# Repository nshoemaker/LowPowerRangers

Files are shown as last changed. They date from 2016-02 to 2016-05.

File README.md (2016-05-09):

# LowPowerRangers
###2D TOF RF Tracking from a Single Sensor Bar
####18-549 Capstone Project for Team 20
####Clayton Ritcher, Nora Shoemaker, and Shashwat Srivastava
#####For more information, check out our website
https://www.ece.cmu.edu/~ece549/spring16/team20/website/
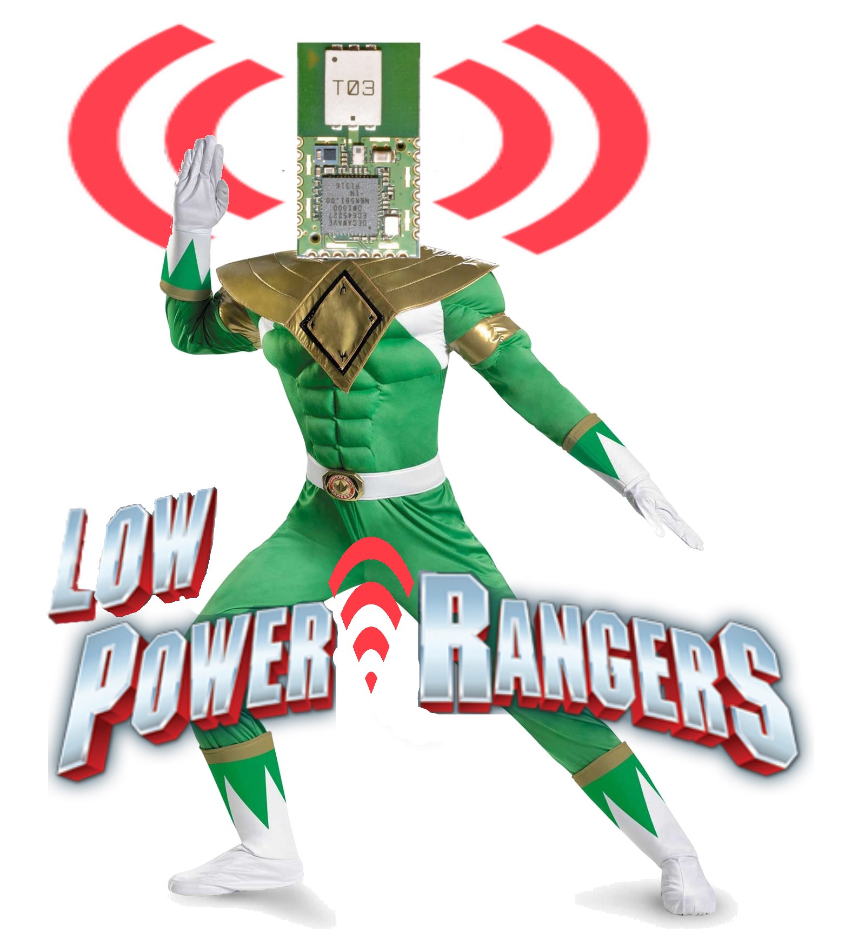
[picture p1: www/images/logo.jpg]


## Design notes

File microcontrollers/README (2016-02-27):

To Build:

	For each microcontroller (one time):
		1) Remove the 3 volt regulator
		2) Plug the ISP programmer cable into the board (the actual cable faces away from ground and 5v)
		3) cd into the bootloader directory
		4) Run 'sudo make atmega328_pro8_isp'
		5) Put the 3 volt regulator back

	For tags:
		1) cd into the src/tag folder
		2) Run 'sudo make program'

	For anchors:
		1) cd into the src/anchor folder
		2) Run 'sudo make program'

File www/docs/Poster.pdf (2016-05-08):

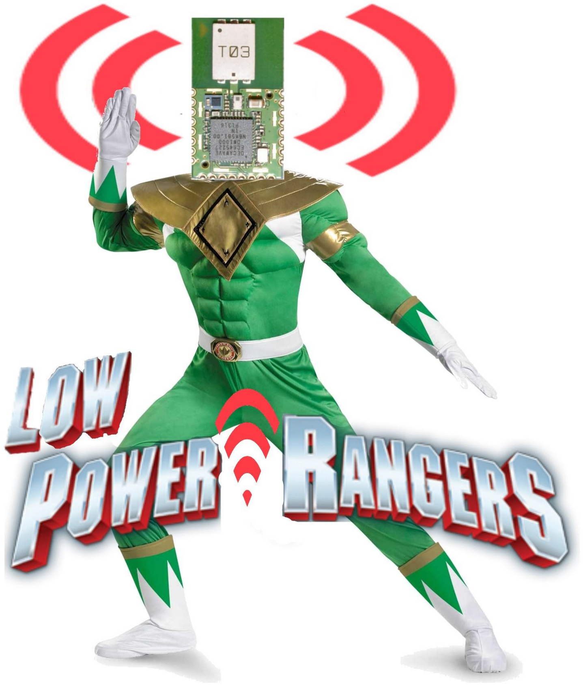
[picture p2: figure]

Electrical and Computer Engineering Department Carnegie Mellon University Clayton Ritcher, Nora Shoemaker, Shashwat Srivastava {critcher, nshoemak, shashwas}@andrew.cmu.edu
https://www.ece.cmu.edu/~ece549/spring16/team20/website/

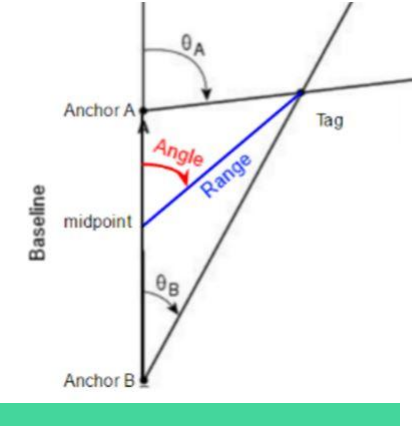
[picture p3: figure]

## Communication Protocol

## Concept

### 18-549 Embedded Design Capstone S’16

## Hardware

The goal of our project is to create a real-time, indoor localization web API for measuring and reporting relative angle and range information of an object.

Using three Ultrawide Band (UWB) radios and a time of flight (TOF) based ranging protocol, we can successfully track the range of an object within 5% accuracy and angle within 10° (0.15 rad) accuracy.

In order to collect ranging
information | with | the | UWB
radios, we needed to define and
implement | our | | own
communication protocol. Below is a diagram showing the
messages needed to be passed between the two Anchors and the Tag in order to collect TOF information to determine range.

A large part of our project involved research
into | how | baseline | distances | (between
Anchors) affect the accuracy of the angle and range measurements.

## Baseline Research

We created a single printed circuit board (PCB) for both the Anchors and the Tag (the roles are defined in software, not hardware). The boards let us connect the DWM1000 UWB
radios | to | our | ATMEGA328
microcontrollers.

## Architecture

The trilateration equations show that as the baseline increases, angle measurements
become | more | resilient | to | individual
measurement error. This is supported by the top graph above. Additionally, the equations show that range measurements are more robust to noise as the range grows compared to the baseline. Again, our bottom graph follows this trend.

All data shown was collected at an angle of 45°.

## Quick Facts

- To achieve our 10 cm single tag-anchor range accuracy, message flight time measurements must be accurate within ⅓ of a nanosecond
- That’s nearly 100 times shorter than one clock cycle of our radio or microprocessor
- Clock drift on the radios, if not handled in the ranging protocol, can cause error of up to 12 meters
- UWB-based localization is very new. BLE or WiFi solutions have ~5m accuracy

Indoor localization has many uses:
- Indoor GPS-style navigation
- Robotics
- Targeted advertising
- Inventory tracking
- Augmented reality
and more

## Applications

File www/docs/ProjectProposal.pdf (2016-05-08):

# 18-549 Design Proposal

## Team 20: Low Power Rangers

Clayton Ritcher (critcher)
Nora Shoemaker (nshoemak)
Shashwat Srivastava (shashwas)

2/12/2016

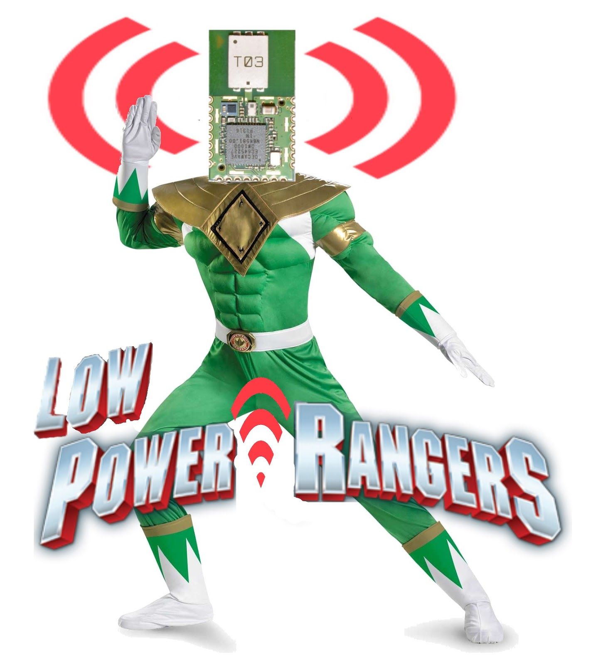
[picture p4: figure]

# Table of Contents

Project Description | 2
Design Requirements | 2
Architecture | 3
Design Trade Studies | 4
System Description/Depiction | 6
Schedule | 8
Team Member Responsibilities | 10
Budget | 10
Risk Management | 11
Related Work | 12
References | 12

# Project Description

The main goal of this project is to use two Decawave DWM1000 ultra wide band (UWB) radio transceiver to collect angle of arrival and range information of a single other transceiver relative to the measurement unit. We will call the two transceivers in the measurement device Anchors, and the other device a Tag. Because angle of arrival detection has never been done before publicly with UWB, we want to explore the space and experiment with different configurations in order to evaluate what kind of accuracy we can achieve at various baseline distances between the Anchors.

On top of this, we would like to expose a web API for accessing the angle of arrival and range data collected. Applications that would like to use these data can then be built on top of our API.

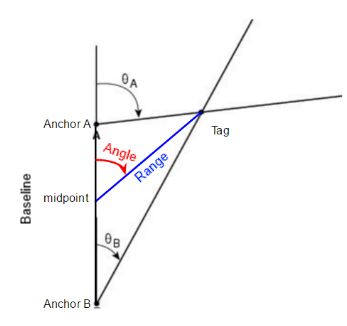
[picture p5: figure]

# Design Requirements

Motivations:

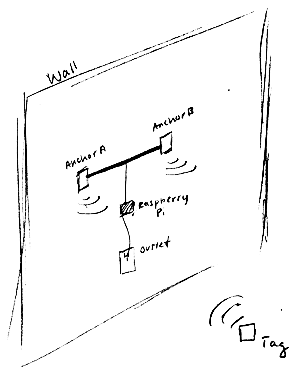
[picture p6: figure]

M1. Locationfocused client applications want near realtime range and angle tracking of users.
M2. Client applications want information to be easily accessible and platform independent.
M3. Useful client applications will necessitate that the tracked object be mobile and always on.
M4. We want to keep the scope of our project reasonable if a feature does not supplement the demo, it is likely unnecessary.

Primary Requirements:
PR1. Range and angle data shall be available through a webaccessible API [M2].
PR2. Range and angle data should be available through the API in under two seconds after the data is collected [M1].
PR3. Range and angle data shall be collected at a rate of at least 1 Hz [M1].
PR4. Tag shall be portable (battery powered) as to allow tracking of mobile objects [M3].
PR5. Tag shall be able to run at least two hours on a full battery [M3].
PR6. Webserver shall be able to handle load of up to 100 requests per second [M2,M4].

Stretch Goals (possible extensions, in no particular order):
SG1. A ‘radar’ app for finding your keys, phone, etc (anything with a Tag attached).
SG2. A client app that integrates the system with IFTTT, (https://ifttt.com/) allowing actions such as turning on the TV when you sit on the couch.
SG3. Add a third Anchor, making an ‘L’ with the other two, in order to measure both the vertical and horizontal angle of arrival.
SG4. Ability to change the baseline distance between the measurement Anchors without manually changing the configuration parameters in the code.

# Architecture

Below is a physical architectural diagram showing the components of our project and the various forms of communication that the components use amongst themselves.

UWB communication is used to obtain the range data between each of the Anchors and the Tag using TOF analysis. Microcontrollers on each Tag/Anchor talk to the DWM1000 chip through SPI. Once each of the Anchors know their distance from the Tag, this information will be sent to the Raspberry Pi, along with the Tag ID. The Raspberry Pi will then compute the angle of arrival based on the two range estimates and the known distance between the Anchors. Once the angle of arrival is calculated, the range between the Tag and the midpoint of the Anchors will be calculated and these two pieces of data will be sent to the web server, with the Tag and measurement device IDs, through an internal API call.

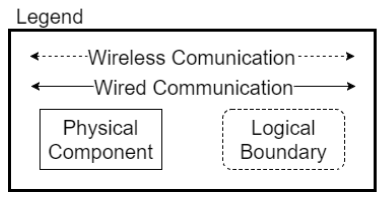
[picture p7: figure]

# Design Trade Studies

A major trade study we conducted involved the general message protocol that we plan to use for ranging. To fulfill our requirements, our system must be able to calculate the distance from each of the two Anchors to the Tag at a rate of at least 1 Hz. Additionally, we wish to keep the power consumption of the Tag low so that it can be battery powered, and we wish to achieve the highest accuracy that we can. Ideally, the protocol that we use will allow for Tag discovery, as well.

One ranging protocol is Singlesided twoway ranging (SS-TWR). This protocol involves two messages total and allows a propagation time to be calculated by the initiating device based on the time the other device takes to reply, Treply and the round trip time experienced by the initiating device, Tround

. Then, the propagation
time can be calculated as:
Tprop = (T | T | ) 2

1

### round − reply

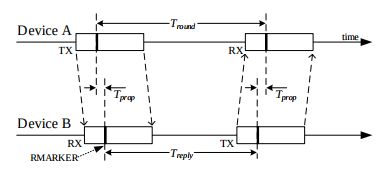
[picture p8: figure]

Figure 2. The twomessage ranging scheme defined by SS-TWR.

1

Another ranging protocol we considered is Doublesided twoway ranging (DS-TWR). This protocol uses three messages and varies from SS-TWR in two main ways because of the extra message. First, this protocol can account for error due to clock drift between the devices. Second, this protocol calculates the range on the second device, not the initiator.

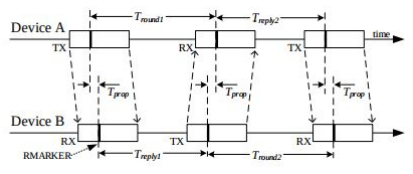
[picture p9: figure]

Figure 3. The threemessage ranging scheme defined by DS-TWR.

1

With DS-TWR, the propagation time is then calculated as:

### Tprop =

(T | T | − T | T | )
| round1 * round2 | | reply1 * reply2
(T | + T | + T | + T | )
round1 | round2 | reply1 | reply2

A final ranging protocol we considered is Broadcastdoublesided ranging (BDSR). This protocol is similar to DS-TWR, but cuts down on the number of messages needed when the initiator is ranging with multiple other devices. This is achieved by having the Tag broadcast its messages and letting all other devices respond in a stagger.

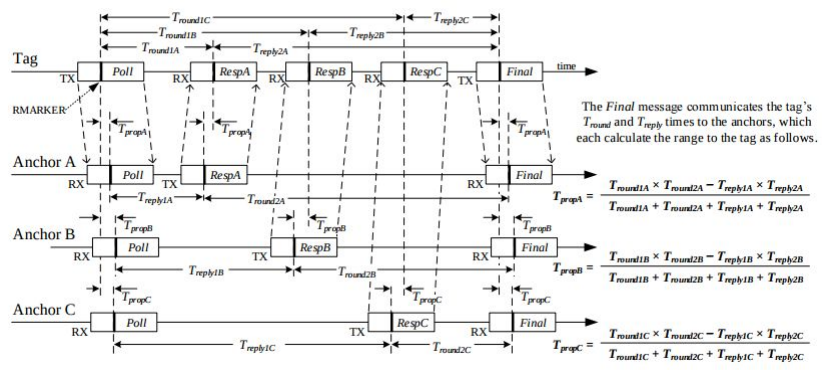
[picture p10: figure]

Figure 4. BDSR with three other devices (Anchor A-C). Each Anchor calculates its range from the initiator as shown on the right.

1

Using the criteria listed above, we decided to evaluate these three protocols against one another:

(All Scores Between 1 and 5) | Weight (higher is more important) | SS-TWR | DS-TWR | BDSR
Possible Update Rate | 2 | 4 | 1 | 4
Tag Power Consumption | 3 | 1 | 3 | 4
Achievable Accuracy | 4 | 1 | 4 | 4
Tag Discovery | 1 | 0 | 0 | 5
Total (higher is better) | | 15 | 27 | 41

As you can see, we decided on BDSR as our ranging protocol. One reason for this is that, for two Anchors, each ranging session only requires four messages. DS-TWR would require six (three for each Anchor), and while SS-TWR only takes four as well, the number of messages needs scales twice as fast with the number of Anchors for SS-TWR. Thus, BDSR will perform better if we decide to add Anchors.

Additionally, because the Tag initiates the ranging (and thus is not constantly listening) and only has to send two messages (regardless of the number of Anchors), BDSR allows for the lowest Tag power consumption. Furthermore, BDSR allows for measurements as accurate as DS-TWR, and more accurate than SS-TWR (which does not handle clock drift). Finally, because the Tag only sends broadcast messages in BDSR, Tag discovery is integrated (the devices do not need to know each others addresses).

# System Description/Depiction

The goal of our system is to collect range and angle of arrival information about a single Tag, relative to a measurement device, over a period of time and create a web API from which applications can retrieve this information.

The diagram shows the interaction between various components going through the process of collecting range and angle of arrival information for a single point in time.
Steps:
1. Poll Tag polls both Anchors in a broadcasted message.
2. ResponseA Anchor A sends response to Tag. 3.ResponseB Anchor B sends response to Tag. 4.Final Tag broadcasts Final message to Anchors containing enough information for each Anchor to estimate range.
5.Anchors tell Raspberry Pi their newly calculated range values.
6. Raspberry Pi calculates angle of arrival and then makes API call to store new data on the Webserver.

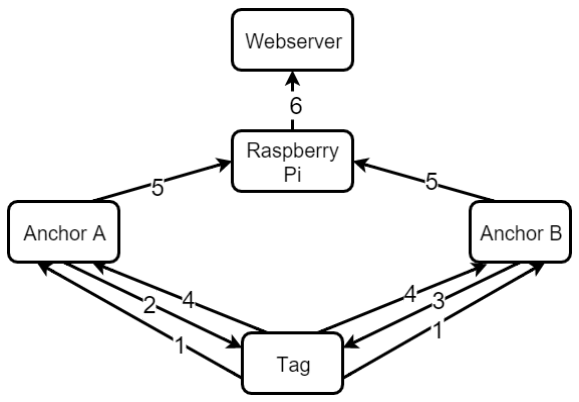
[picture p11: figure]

Part of the interaction is the UWB
communication protocol we will use. We chose a variant of the BDSR protocol described in Figure 4. Because we only intend to use two Anchors, we plan on using something similar to the protocol below:

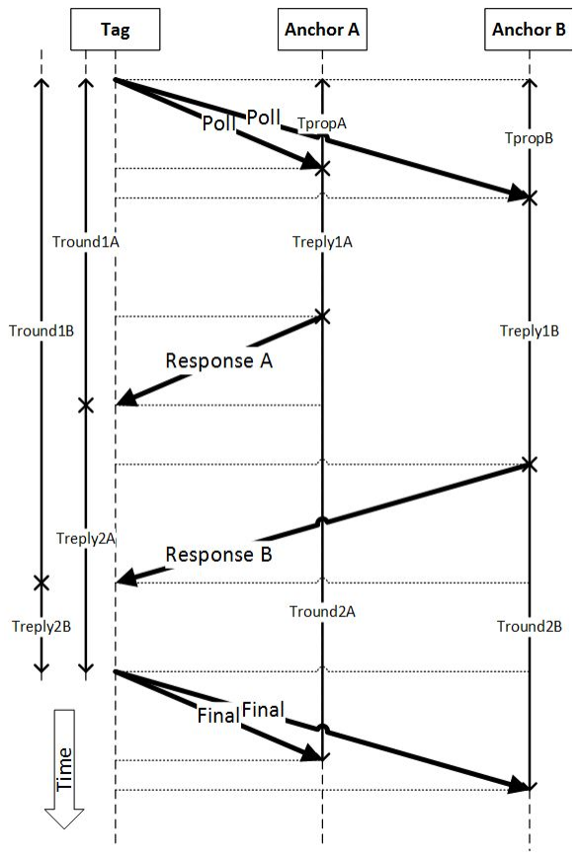
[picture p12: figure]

Protocol Step | Information Sent
Poll | Range Session ID, Tag Address
Response | Range Session ID, Anchor ID
Final | Range Session ID, Tag Address, Tround1A, Treply2A, Treply1B, Treply2B

With this protocol, the propagation times, and thus the ranges can be determined for Anchor A and Anchor B as follows:

### TpropA =

(T | T | − T | T | )
| round1A * round2A | | reply1A * reply2A
(T | + T | + T | + T | )
round1A | round2A | reply1A | reply2A

### TpropB =

(T | T | − T | T | )
| round1B * round2B | | reply1B * reply2B
(T | + T | + T | + T | )
round1B | round2B | reply1B | reply2B

One thing to note is that when we refer to a ‘Tag’ or an ‘Anchor’ we are referring to the microcontroller / DWM1000 pairs, as specified in the architecture section earlier. Therefore, when we say something such as

‘the Tag sends a message’ we are abstracting away the fact that the microcontroller is actually setting registers on the DWM1000 over SPI in order to command the module to send the message.

At a higher level, our project itself has very little user interaction (by design, for ease of use); the user simply needs to carry a Tag with them while in the presence of a measurement device to use the system itself. However, here is what we would expect user interaction with a client application to look like:

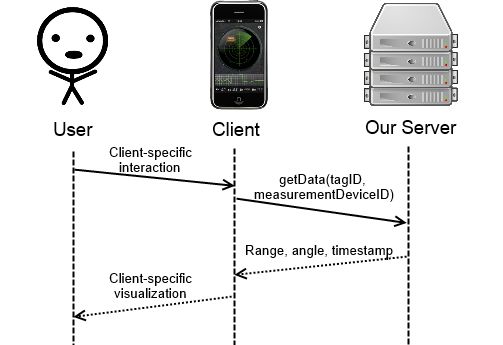
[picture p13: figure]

# Schedule

Because we have such a hard deadline presented by the demo, we are planning on finishing our project in six weeks (half the time left in the semester). We want to make clear that we are planning on finishing in six weeks with the expectation that it will end up taking longer than that to finish our nonstretch goals. We want to factor in our inevitable misestimations and allow for significant padding so that we can truly be finished by the demo date.

(Please zoom in on the schedule on the next page for full details)

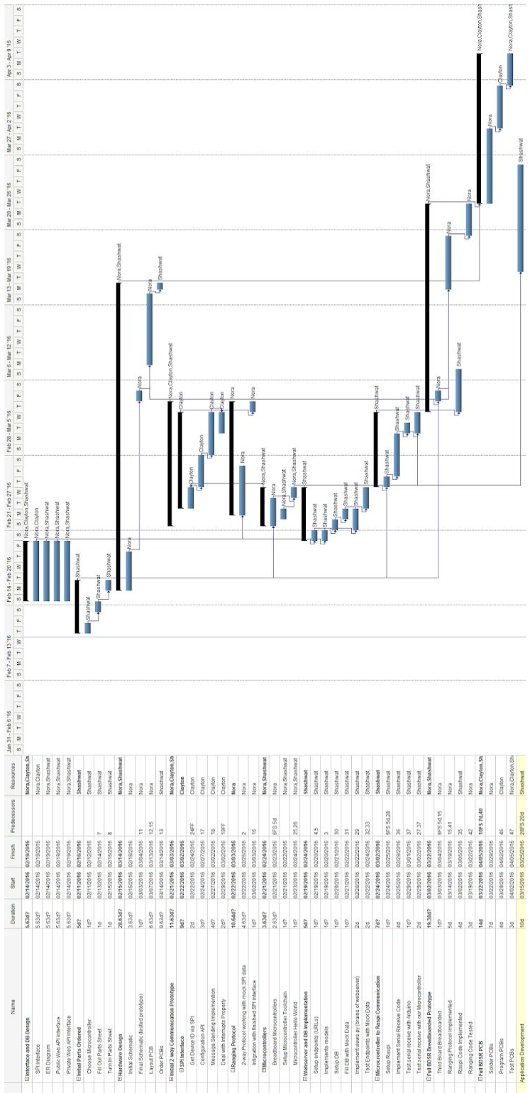
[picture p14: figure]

# Team Member Responsibilities

We plan on breaking down the project into smaller tasks. Each task will have an “owner” who is in charge of it being completed. While it is the owner’s responsibility to finish the task, everyone can work on it. See the schedule for finer grained breakdown of tasks.

Task | Person in Charge
Creating an SPI interface to control the UWB module | Clayton Ritcher
Creating/Implementing a protocol for Tag discovery and ranging | Nora Shoemaker
Sending data from the Microcontroller to the Raspberry Pi | Clayton Ritcher
Sending data from the Raspberry Pi to the server | Shashwat Srivastava
Making data available to an API | Shashwat Srivastava
Making application on top of data (NOTE: Stretch goal) | Shashwat Srivastava
Web Master | Nora Shoemaker
Creating the PCB Design | Nora Shoemaker
Hardware Construction | Nora Shoemaker

# Budget

Part | Cost | Link for part | Quantity | Total Cost
Raspberry Pi | $49.95 | https://www.sparkfun.com/products/13724 | 1 | $49.95
Wifi Adapter for Raspberry Pi | $14.95 | https://www.sparkfun.com/products/13677 | 1 | $14.95
Decawave DWM1000 Module | $20.50 | http://www.semiconductorstore.com/cart/pc/viewPrd.asp?idproduct=50013 (http://www.semiconductorstore.com/cart/pc/viewPrd.asp?idproduct=50013) | 7 | $143.50
Pocket AVR Programmer | $14.95 | https://www.sparkfun.com/products/9825 | 2 | $29.90
Plastic Breadboard | $4.95 | https://www.sparkfun.com/products/11317 | 3 | $14.85
ATMega 328 | $3.70 | http://www.mouser.com/ProductDetail/Atmel/ATMEGA328P-PU/?qs=K8BHR703ZXguOQv3sKbWcg%3D%3D&gclid=CjwKE | 7 | $25.90

| | AiA__C1BRDqyJOQ8_Tq230SJABWBSx nq4t6W6Tp6DzcyCqWLSnFywsY_JBwMr pBtNGaJ_HgZhoCJADw_wcB
Capacitors/resistors/ batteries | $50 | | | $50
PCB Fabricating Cost | $18 | | 5 | $90
Shipping charges(being conservative here) | $100 | | | $100
FTDI Breakout Board | $14.95 | https://www.sparkfun.com/products/9873 | 3 | $44.85
Total | | | | $563.90

# Risk Management

We have identified the use of the Decawave DWM1000 chip technology as a significant risk we are choosing to take on with this project. The use of this new technology, along with the fact that we are using it to find angle of arrival information, something that no one has done publicly yet, is a risk we have identified and thought a lot about. Our first mitigation strategy thus far has been to reduce the scope of the project. This doesn’t mitigate the risk of working with the technology entirely, but it does help by allowing us to budget more time towards getting things working in the likely chance that this will be a very hard, time consuming task. Our second mitigation strategy has been to add a significant amount of padding to our schedule and essentially frontload much of the work with the hope of gaining information as quickly as possible about the problems we will incur.

Another risk we have identified is our team’s relative lack of experience with embedded programming, especially when it comes to interfacing with real hardware. Every member of our team took 18-349 in Fall 2014. Because of this, we have plenty of experience with simulated hardware, but less experience with real, physical hardware at the embedded level. We all have a background in hobby electronics using Arduino and Raspberry Pi, but we understand that this project will be different and for that reason we expect a significant learning curve. In order to mitigate this risk, we have chosen a project that will involve the use of a single sensor and a single microcontroller. We scale by creating multiples copies of the same setup. Another mitigation strategy we would like to put in place is that we will require a fully working, breadboarded prototype before we fab our PCBs.

# Related Work

One of the primary reasons we chose our project was to research the feasibility of making angle of arrival calculation using ultrawideband transceivers, as it has not been publicly demonstrated as of yet. There are other solutions that tackle similar issues, though.

For instance, indoor localization systems using wifi

2
, BLE

3
, or even UWB

4 could all be used for similar applications as our system. Wifi and BLE systems are less accurate than UWB, though, and UWB indoorlocalization systems still require installation of at least three Anchors in each area, on separate walls. Our system would be able to support many similar applications (such as those listed in earlier sections) with the installation of a single device (with two contained Anchors) on a wall in the room. The selfcontained property of our Anchors device also means that it could be mounted to something other than a wall, such as a robot, and used to calculate relative range and angle information to a tag from what it is mounted to.

# References

1. http://www.decawave.com/support/download/file/nojs/725
2. http://redpin.org/
3. http://estimote.com/
4. http://www.timedomain.com/

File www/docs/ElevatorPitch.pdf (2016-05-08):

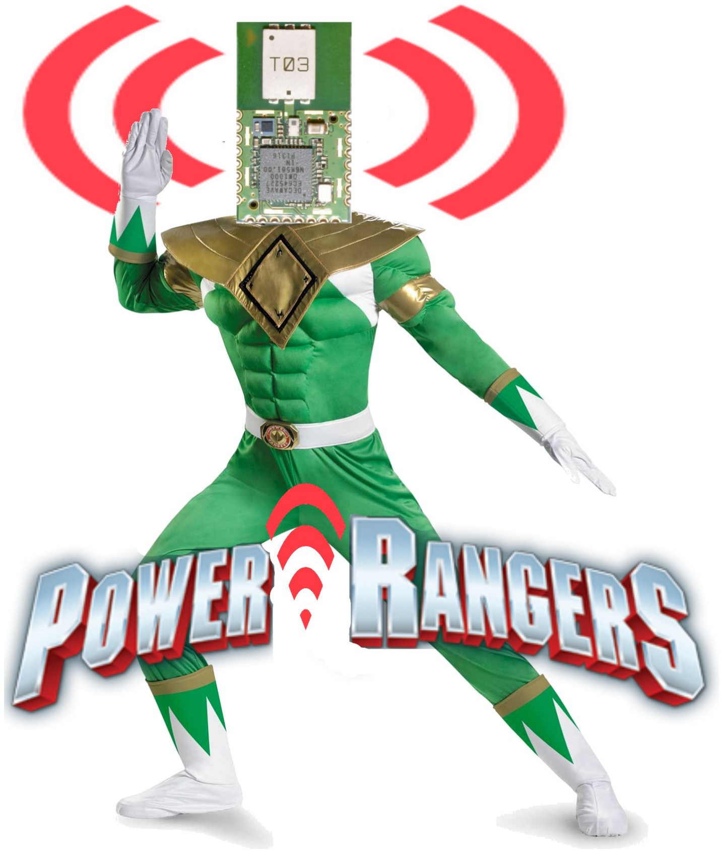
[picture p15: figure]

## Team 20 Clayton Ritcher Nora Shoemaker Shashwat Srivastava

## Concept

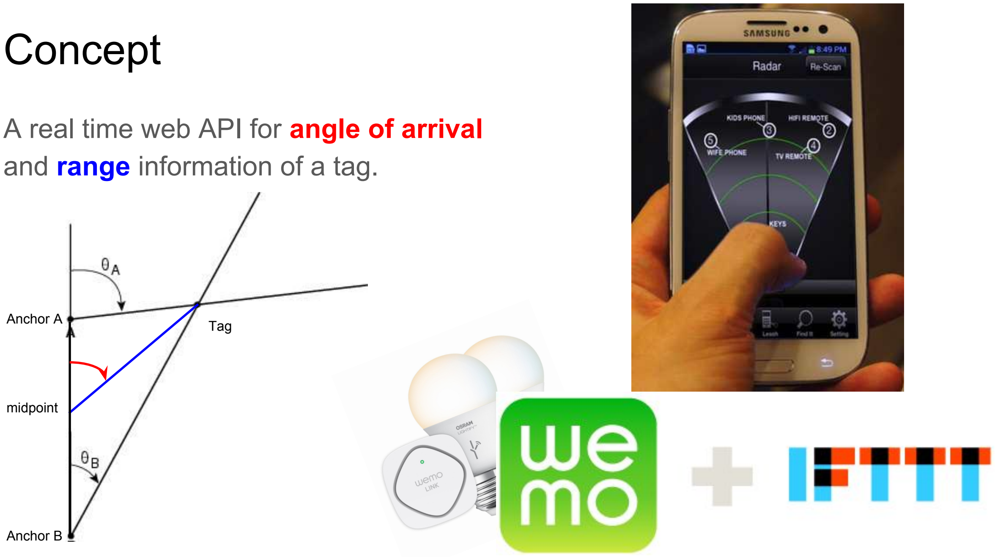
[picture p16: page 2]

A real time web API for angle of arrival and range information of a tag.

midpoint

Anchor A

Anchor B

Tag

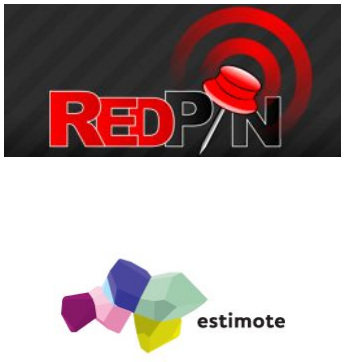
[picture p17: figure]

## Competitive Analysis

- Wifi-based
- Signal strength, fingerprint
- Often 5-10 m accuracy
- BLE Beacons
- Signal strength
- ~5 m accuracy
- UWB
- TOF
- < 1m accuracy
- Often a custom system
installation, very expensive

## Requirements

- Range and angle data shall be available to web accessible API in under two seconds after the data is collected.
- Range and angle data shall be collected at a rate of at least 1 Hz.
- Tag shall be portable (battery powered).
- Anchors and Raspberry Pi shall be powered from an outlet.
- Tag shall be able to run at least two hours on a full battery.

## Tech Specs

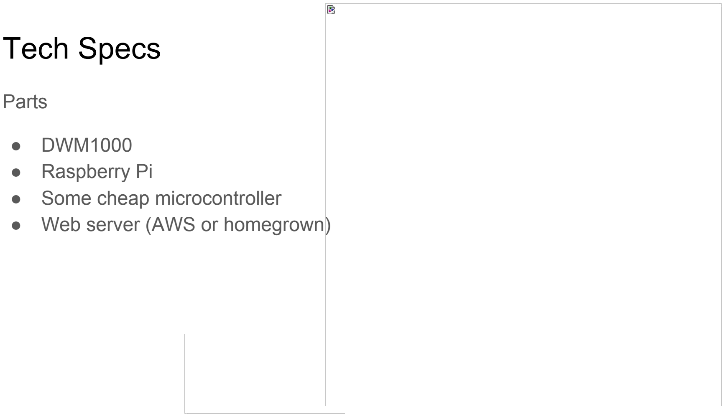
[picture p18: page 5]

Parts

- DWM1000
- Raspberry Pi
- Some cheap microcontroller
- Web server (AWS or homegrown)

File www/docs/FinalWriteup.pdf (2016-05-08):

# 18-549 Final Write Up

## Team 20: Low Power Rangers

Clayton Ritcher (critcher)
Nora Shoemaker (nshoemak)
Shashwat Srivastava (shashwas)

5/7/2016


# Table of Contents

Project Description | 2
Design Requirements | 2
Architecture | 3
Design Trade Studies | 4
System Description/Depiction | 6
Schedule | 8
Team Member Responsibilities | 10
Budget | 10
Risk Management | 11
Related Work | 12
References | 12

# Project Description

The main goal of this project is to use two Decawave DWM1000 ultra wide band (UWB) radio transceivers to collect angle of arrival and range information of a single other transceiver, relative to the measurement unit. We will call the two transceivers in the measurement device Anchors, and the other device a Tag. Because angle of arrival detection has never been done before publicly with UWB, we want to explore the space and experiment with different configurations in order to evaluate what kind of accuracy we can achieve at various baseline distances between the Anchors.

On top of this, we would like to expose a web API for accessing the angle of arrival and range data collected. Applications that would like to use these data can then be built on top of our API.


# Design Requirements

Motivations:


M1. Locationfocused client applications want near realtime range and angle tracking of users.
M2. Client applications want information to be easily accessible and platform independent.
M3. Useful client applications will necessitate that the tracked object be mobile and always on.
M4. We want to keep the scope of our project reasonable if a feature does not supplement the demo, it is likely unnecessary.

Primary Requirements:
PR1. Range and angle data shall be available through a webaccessible API [M2].
PR2. Range and angle data should be available through the API in under two seconds after the data is collected [M1].
PR3. Range and angle data shall be collected at a rate of at least 1 Hz [M1].
PR4. Tag shall be portable (battery powered) as to allow tracking of mobile objects [M3].
PR5. Tag shall be able to run at least two hours on a full battery [M3].
PR6. Webserver shall be able to handle load of up to 100 requests per second [M2,M4].

Stretch Goals (possible extensions, in no particular order):
SG1. A ‘radar’ app for finding your keys, phone, etc (anything with a Tag attached).
SG2. A client app that integrates the system with IFTTT, (https://ifttt.com/) allowing actions such as turning on the TV when you sit on the couch.
SG3. Add a third Anchor, making an ‘L’ with the other two, in order to measure both the vertical and horizontal angle of arrival.
SG4. Ability to change the baseline distance between the measurement Anchors without manually changing the configuration parameters in the code.

# Architecture

Below is a physical architectural diagram showing the components of our project and the various forms of communication that the components use amongst themselves.

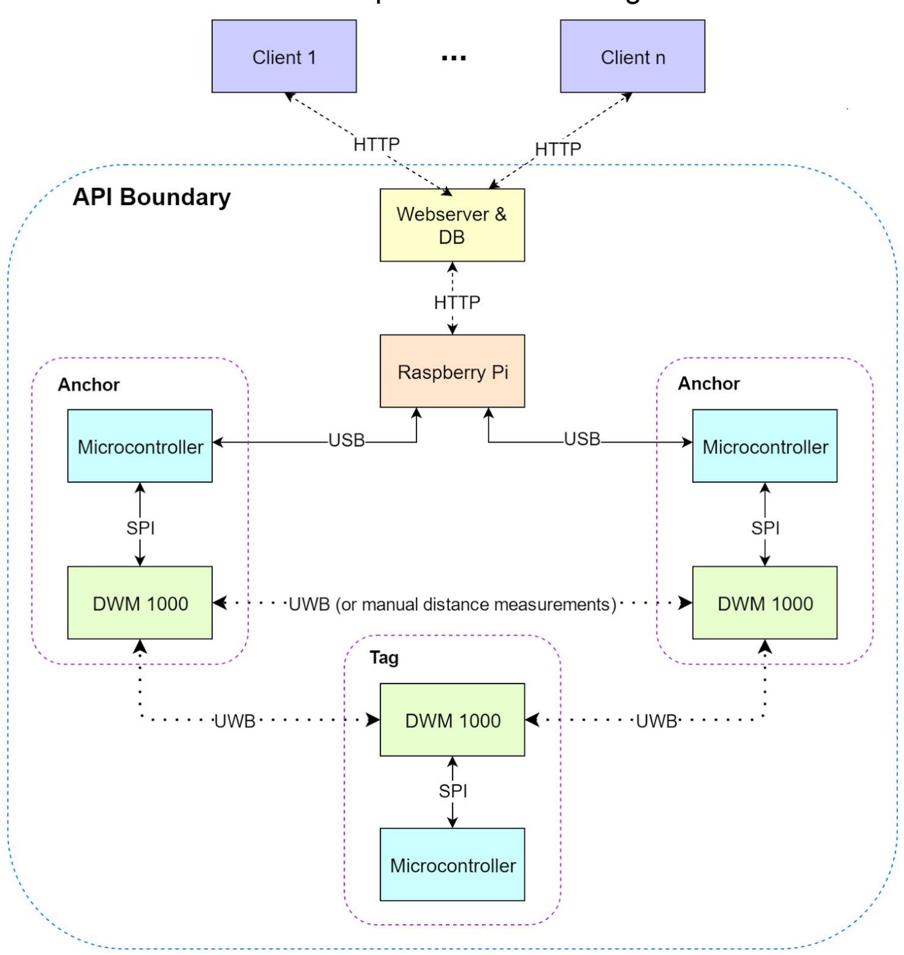
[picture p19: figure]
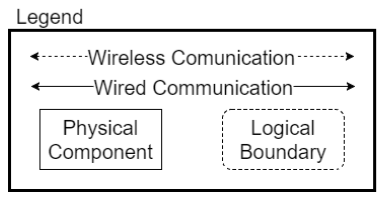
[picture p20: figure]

UWB communication is used to obtain the range data between each of the Anchors and the Tag using TOF analysis. Microcontrollers on each Tag/Anchor talk to the DWM1000 chip through SPI. Once each of the Anchors know their distance from the Tag, this information will be sent to the Raspberry Pi, along with the Tag ID. The Raspberry Pi will then compute the angle of arrival based on the two range estimates and the known distance between the Anchors. Once the angle of arrival is calculated, the range between the Tag and the midpoint of the Anchors will be calculated and these two pieces of data will be sent to the web server, with the Tag and measurement device IDs, through an internal API call.

# Design Trade Studies

A major trade study we conducted involved the general message protocol that we plan to use for ranging. To fulfill our requirements, our system must be able to calculate the distance from each of the two Anchors to the Tag at a rate of at least 1 Hz. Additionally, we wish to keep the power consumption of the Tag low so that it can be battery powered, and we wish to achieve the highest accuracy that we can. Ideally, the protocol that we use will allow for Tag discovery, as well.

One ranging protocol is Singlesided twoway ranging (SS-TWR). This protocol involves two messages total and allows a propagation time to be calculated by the initiating device based on the time the other device takes to reply, Treply and the round trip time experienced by the initiating device, Tround

. Then, the propagation
time can be calculated as:
Tprop = (T | T | ) 2

1

### round − reply


Figure 2. The twomessage ranging scheme defined by SS-TWR.

1

Another ranging protocol we considered is Doublesided twoway ranging (DS-TWR). This protocol uses three messages and varies from SS-TWR in two main ways because of the extra message. First, this protocol can account for error due to clock drift between the devices. Second, this protocol calculates the range on the second device, not the initiator.


Figure 3. The threemessage ranging scheme defined by DS-TWR.

1

With DS-TWR, the propagation time is then calculated as:

### Tprop =

(T | T | − T | T | )
| round1 * round2 | | reply1 * reply2
(T | + T | + T | + T | )
round1 | round2 | reply1 | reply2

A final ranging protocol we considered is Broadcastdoublesided ranging (BDSR). This protocol is similar to DS-TWR, but cuts down on the number of messages needed when the initiator is ranging with multiple other devices. This is achieved by having the Tag broadcast its messages and letting all other devices respond in a stagger.


Figure 4. BDSR with three other devices (Anchor A-C). Each Anchor calculates its range from the initiator as shown on the right.

1

Using the criteria listed above, we decided to evaluate these three protocols against one another:

(All Scores Between 1 and 5) | Weight (higher is more important) | SS-TWR | DS-TWR | BDSR
Possible Update Rate | 2 | 4 | 1 | 4
Tag Power Consumption | 3 | 1 | 3 | 4
Achievable Accuracy | 4 | 1 | 4 | 4
Tag Discovery | 1 | 0 | 0 | 5
Total (higher is better) | | 15 | 27 | 41

As you can see, we decided on BDSR as our ranging protocol. One reason for this is that, for two Anchors, each ranging session only requires four messages. DS-TWR would require six (three for each Anchor), and while SS-TWR only takes four as well, the number of messages needs scales twice as fast with the number of Anchors for SS-TWR. Thus, BDSR will perform better if we decide to add Anchors.

Additionally, because the Tag initiates the ranging (and thus is not constantly listening) and only has to send two messages (regardless of the number of Anchors), BDSR allows for the lowest Tag power consumption. Furthermore, BDSR allows for measurements as accurate as DS-TWR, and more accurate than SS-TWR (which does not handle clock drift). Finally, because the Tag only sends broadcast messages in BDSR, Tag discovery is integrated (the devices do not need to know each others addresses).

# System Description/Depiction

The goal of our system is to collect range and angle of arrival information about a single Tag, relative to a measurement device, over a period of time and create a web API from which applications can retrieve this information.

The diagram shows the interaction between various components going through the process of collecting range and angle of arrival information for a single point in time.
Steps:
1. Poll Tag polls both Anchors in a broadcasted message.
2. ResponseA Anchor A sends response to Tag. 3.ResponseB Anchor B sends response to Tag. 4.Final Tag broadcasts Final message to Anchors containing enough information for each Anchor to estimate range.
5.Anchors tell Raspberry Pi their newly calculated range values.
6. Raspberry Pi calculates angle of arrival and then makes API call to store new data on the Webserver.


Part of the interaction is the UWB
communication protocol we will use. We chose a variant of the BDSR protocol described in Figure 4. Because we only intend to use two Anchors, we plan on using something similar to the protocol below:


Protocol Step | Information Sent
Poll | Range Session ID, Tag Address
Response | Range Session ID, Anchor ID
Final | Range Session ID, Tag Address, Tround1A, Treply2A, Treply1B, Treply2B

With this protocol, the propagation times, and thus the ranges can be determined for Anchor A and Anchor B as follows:

### TpropA =

(T | T | − T | T | )
| round1A * round2A | | reply1A * reply2A
(T | + T | + T | + T | )
round1A | round2A | reply1A | reply2A

### TpropB =

(T | T | − T | T | )
| round1B * round2B | | reply1B * reply2B
(T | + T | + T | + T | )
round1B | round2B | reply1B | reply2B

One thing to note is that when we refer to a ‘Tag’ or an ‘Anchor’ we are referring to the microcontroller / DWM1000 pairs, as specified in the architecture section earlier. Therefore, when we say something such as

‘the Tag sends a message’ we are abstracting away the fact that the microcontroller is actually setting registers on the DWM1000 over SPI in order to command the module to send the message.

At a higher level, our project itself has very little user interaction (by design, for ease of use); the user simply needs to carry a Tag with them while in the presence of a measurement device to use the system itself. However, here is what we would expect user interaction with a client application to look like:


## Implementation and Construction

## PCB For Tag and Anchor

We decided to create the same PCB design for both Tags and Anchors.This meant the same schematic and board layout. We made this decision for a couple reasons. Using the Atmega328s on both Tag and Anchor boards meant that we would only need to write one SPI driver library to interface with the DWM1000s (whereas we could have had the Raspberry Pi communicate directly with the DWM1000s, but decided against it).

Below is an image of our final schematic. There are three main parts of our schematic.The Atmega328 chip and its associated crystal (left), the FTDI header and voltage regulator (top right), and the DWM1000 module (bottom right).

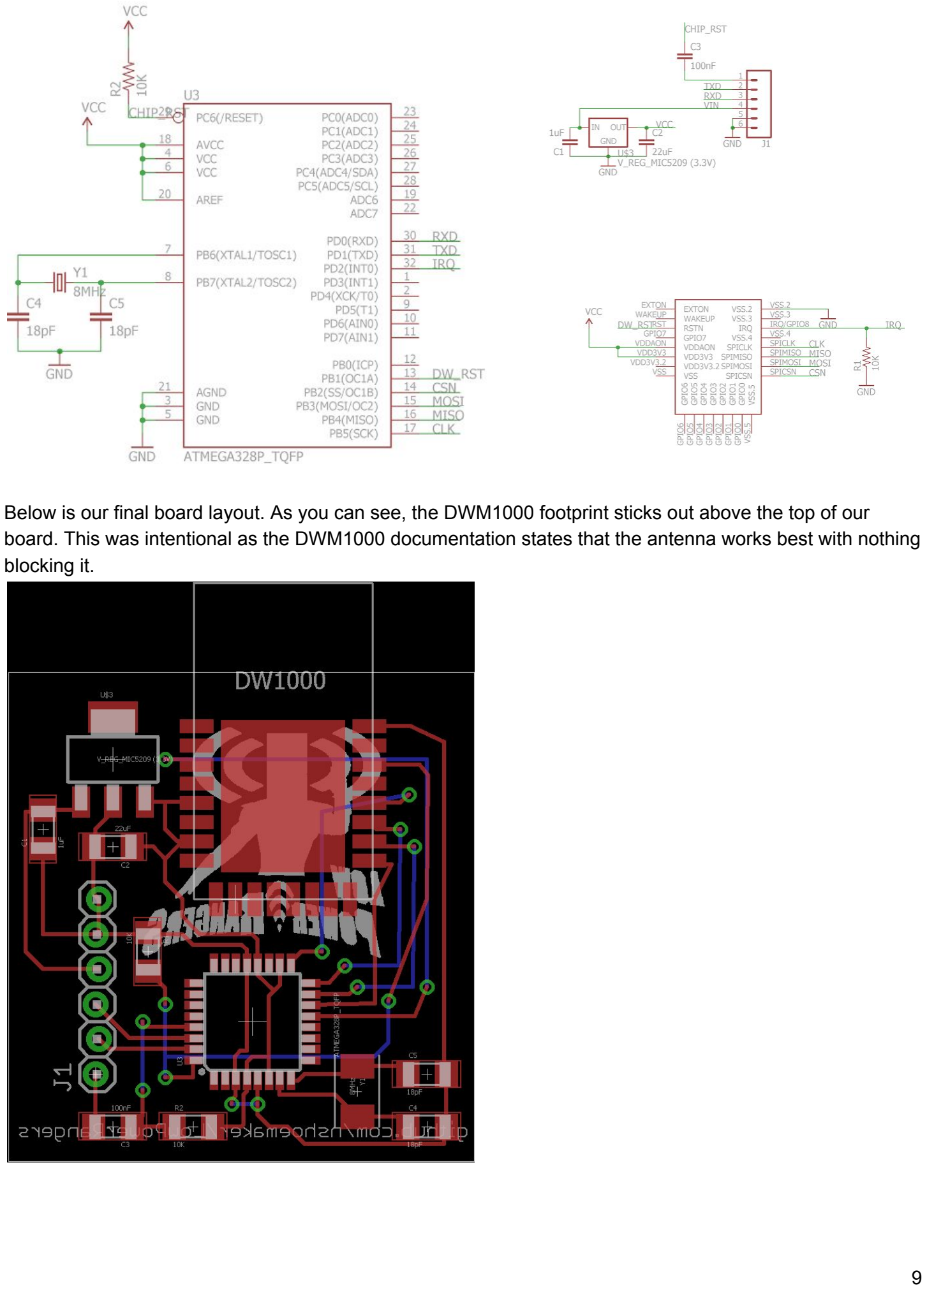
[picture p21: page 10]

Below is our final board layout. As you can see, the DWM1000 footprint sticks out above the top of our board. This was intentional as the DWM1000 documentation states that the antenna works best with nothing blocking it.

Below we have the printed circuit boards we used for both our Tags and Anchors (prebringup). We chose to put components only on one side because we wanted the option of easily laying the Anchors flat against a surface.

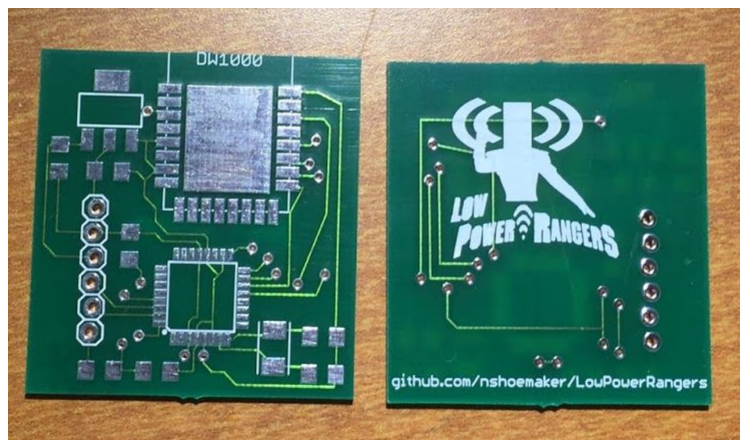
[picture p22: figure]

Here are the circuit boards after we brought them up, with the FTDI cable connected.

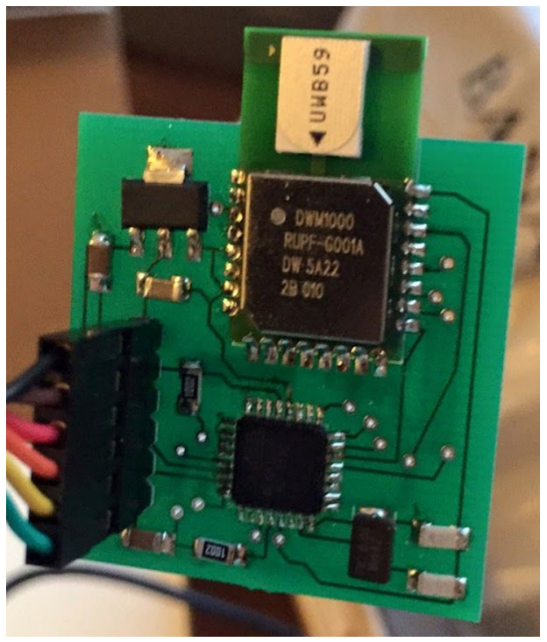
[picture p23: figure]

## Bootloader Circuit

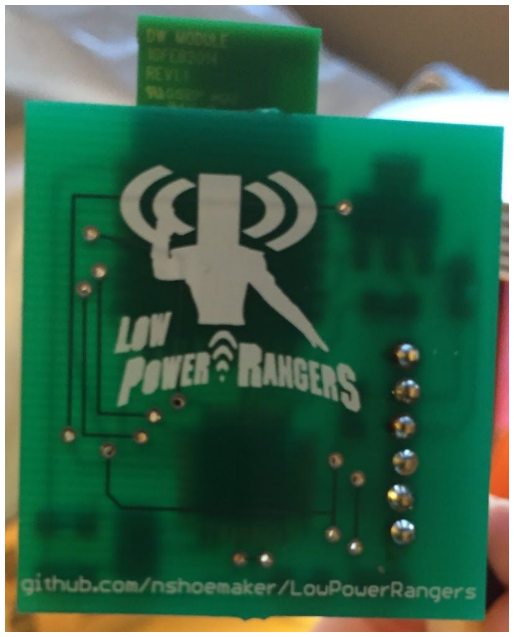
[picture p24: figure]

Another thing worth noting is that we decided to exclude the In-System Programming (ISP) circuit from our Tag and Anchor boards, opting to create an offboard ISP circuit for bootloading our microcontrollers. We decided to breadboard one bootloader circuit for ourselves, using a TQFP test socket.

5 We then soldered
the prebootloaded microcontrollers onto our board, and were able to reprogram them through the FTDI headers as needed. Below is a picture of the test socket and our bootloader circuit.

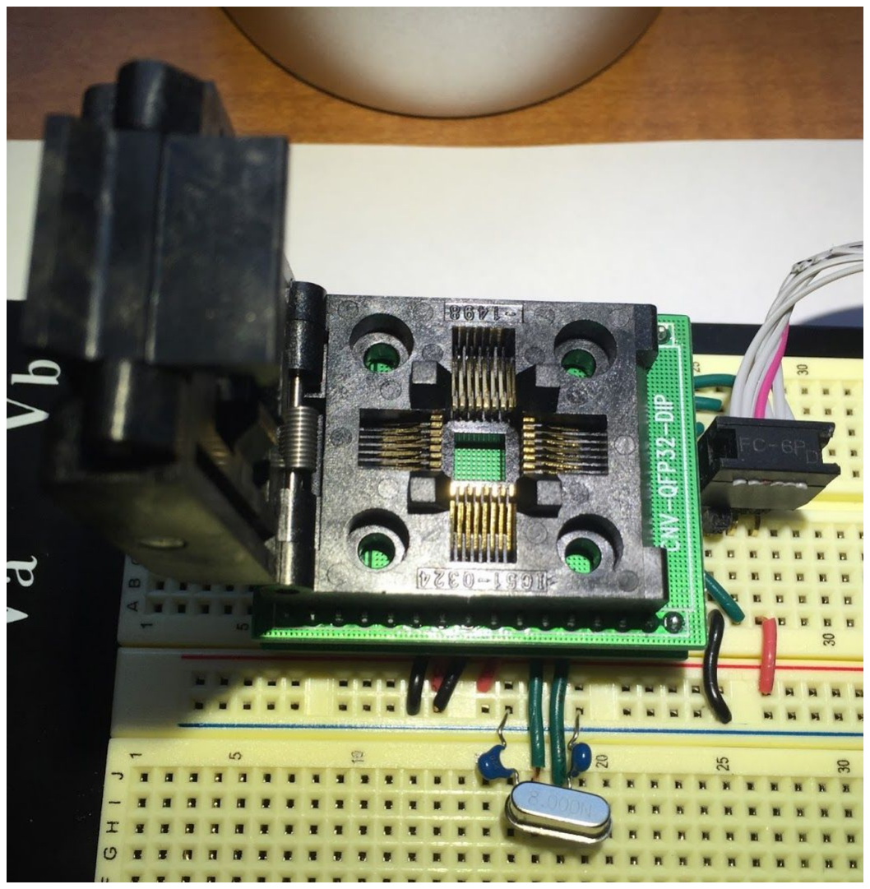
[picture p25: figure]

## Android Application

To demo the project, we built an Android application. The application would be used to display the tracking information in an intuitive way. The app pulls data from the server and then displays it on a grid.


This is the start screen. You can click on the + button to add a tag and give it a name.


Adding the tag then displays it on the screen. It will show up on the screen an appropriate distance away from the anchor positions. The angle will also be the at the correct angle from the anchor position.Below is an example tag position.


The last feature of the application can be accessed by pressing the camera button on the main screen. This will launch the camera application and allow the user to take a picture of their room from the anchor position. It will then draw a line from the bottom of the screen(assumed anchor position) to the place where the tag is. An example image is attached below


# Schedule

Because we have such a hard deadline presented by the demo, we are planning on finishing our project in six weeks (half the time left in the semester). We want to make clear that we are planning on finishing in six weeks with the expectation that it will end up taking longer than that to finish our nonstretch goals. We want to factor in our inevitable misestimations and allow for significant padding so that we can truly be finished by the demo date.

(Please zoom in on the schedule on the next page for full details)


# Team Member Responsibilities

We plan on breaking down the project into smaller tasks. Each task will have an “owner” who is in charge of it being completed. While it is the owner’s responsibility to finish the task, everyone can work on it. See the schedule for finer grained breakdown of tasks.

Task | Person in Charge
Creating an SPI interface to control the UWB module | Clayton Ritcher
Creating/Implementing a protocol for Tag discovery and ranging | Nora Shoemaker
Sending data from the Microcontroller to the Raspberry Pi | Clayton Ritcher
Sending data from the Raspberry Pi to the server | Shashwat Srivastava
Making data available to an API | Shashwat Srivastava
Making application on top of data (NOTE: Stretch goal) | Shashwat Srivastava
Web Master | Nora Shoemaker
Creating the PCB Design | Nora Shoemaker
Hardware Construction | Nora Shoemaker

# BOM

Below is the BOM needed to create our complete platform (two Anchors, one Tag, and a Raspberry Pi).

| | | | Price | $364.40
Description | Link | Quantity | Unit Price | Shipping Charge | Total Price
Programmer | https://www.sparkfun.com/products/9825 | 1 | $14.95 | | $14.95
FTDI Cable | https://www.sparkfun.com/products/9717 | 3 | $17.95 | | $53.85
Raspi | https://www.sparkfun.com/products/13724 | 1 | $49.95 | | $49.95
Wifi Dongle | https://www.sparkfun.com/products/13677 | 1 | $14.95 | | $14.95
Headers | https://www.sparkfun.com/products/12693 | 2 | $0.75 | | $1.50
Decawave | http://www.semiconductorstore.com/cart/pc/viewPrd.asp?idproduct=50013 (http://www.semiconductorstore.com/cart/pc/viewPrd.asp?idproduct=50013) | 3 | $20.50 | | $61.50
Power Supply (for Raspi) | https://www.sparkfun.com/products/13831 | 1 | $7.97 | | $7.97
MIC5209 IC REG LDO 3.3V 0.5A SOT223 | http://www.digikey.com/productdetail/en/MIC5209-3.3YS-TR/576-1274-1-ND/771899 (http://www.digikey.com/product-detail/en/MIC5209-3.3YS-TR/576-1274-1-ND/771899) | 3 | $1.19 | | $3.57

RES SMD 10K OHM 1% 1/4W 1206 | http://www.digikey.com/productdetail/en/ERJ-8ENF1002V/P10.0KFCT-ND/89822 (http://www.digikey.com/product-detail/en/ERJ-8ENF1002V/P10.0KFCT-ND/89822) | 6 | $0.10 | | $0.60
CAP CER 18PF 50V NP0 1206 | http://www.digikey.com/short/3t7p88 | 6 | $0.30 | | $1.80
CAP CER 1UF 25V X7R 1206 | http://www.digikey.com/productdetail/en/CGA5L2X7R1E105K160AA/445-6989-1-ND/2673007 (http://www.digikey.com/product-detail/en/CGA5L2X7R1E105K160AA/445-6989-1-ND/2673007) | 3 | $0.18 | | $0.54
CAP CER 0.1UF (100nF) 50V X7R 1206 | http://www.digikey.com/productdetail/en/C1206C104K5RAC7867/399-1249-1-ND/411524 (http://www.digikey.com/product-detail/en/C1206C104K5RAC7867/399-1249-1-ND/411524) | 3 | $0.07 | | $0.21
8MHz ±30ppm Crystal 18pF 80 Ohm | http://www.digikey.com/productdetail/en/7A-8.000MAAJ-T/887-1448-1-ND/2627016 (http://www.digikey.com/product-detail/en/7A-8.000MAAJ-T/887-1448-1-ND/2627016) | 3 | $0.79 | | $2.37
ATMEGA328P-A UR IC MCU 8BIT 32KB FLASH 32TQFP | http://www.digikey.com/productdetail/en/ATMEGA328P-AUR/ATMEGA328P-AURCT-ND/3789455 (http://www.digikey.com/product-detail/en/ATMEGA328P-AUR/ATMEGA328P-AURCT-ND/3789455) | 3 | $3.70 | | $11.10
SMT Test Socket TQFP-32 Breakout | https://www.adafruit.com/products/1240 | 1 | $44.95 | | $44.95
CAP CER 22UF 25V X7R 1206 | http://www.digikey.com/productdetail/en/samsungelectromechanicsamericainc/CL31A226MOCLNNC/1276-2728-1-ND/3890814 (http://www.digikey.com/product-detail/en/samsung-electro-mechanics-america-inc/CL31A226MOCLNNC/1276-2728-1-ND/3890814) | 10 | $0.29 | | $2.90
PCB order | | 1 | $85.44 | $6.25 | $91.69

# Risk Management

We have identified the use of the Decawave DWM1000 chip technology as a significant risk we are choosing to take on with this project. The use of this new technology, along with the fact that we are using it to find angle of arrival information, something that no one has done publicly yet, is a risk we have identified and thought a lot about. Our first mitigation strategy thus far has been to reduce the scope of the project. This doesn’t mitigate the risk of working with the technology entirely, but it does help by allowing us to budget more time towards getting things working in the likely chance that this will be a very hard, time consuming task. Our second mitigation strategy has been to add a significant amount of padding to our schedule and essentially frontload much of the work with the hope of gaining information as quickly as possible about the problems we will incur.

Another risk we have identified is our team’s relative lack of experience with embedded programming, especially when it comes to interfacing with real hardware. Every member of our team took 18-349 in Fall 2014. Because of this, we have plenty of experience with simulated hardware, but less experience with real, physical hardware at the embedded level. We all have a background in hobby electronics using Arduino and Raspberry Pi, but we understand that this project will be different and for that reason we expect a significant learning curve. In order to mitigate this risk, we have chosen a project that will involve the use of a single sensor and a single microcontroller. We scale by creating multiples copies of the same setup. Another mitigation strategy we would like to put in place is that we will require a fully working, breadboarded prototype before we fab our PCBs.

# Evaluation

A large part of our project involved research into how baseline distances (between Anchors) affect the accuracy of the angle and range measurements. In order to assess how different baselines affect accuracy, we needed to setup some tests. We decided to sweep out a line at 20 cm increments both at 0 degree (directly perpendicular) and 45 degree angles, using a script that collected 50 readings per increment. We repeated this process for baselines of 50, 100, 150, and 200 cm. Below are graphs of the data we collected.

### Theta Error vs. Real Distance at 0 Degrees


### Theta Error vs. Real Distance at 45 Degrees


The derivative of the trilateration equations, with respect to measurement error, shows that theta calculations are more robust to noise as the baseline increases. This can be seen in the graphs above the theta error for larger baselines is consistently lower than the theta error for smaller baselines.


### Range Error vs. Real Distance at 0 Degrees

### Range Error vs. Real Distance at 45 Degrees

The derivative of the trilateration equations, with respect to measurement error, shows that range calculations are less robust to noise as the difference between r1 and r2 (distance to each of the two anchors) grows. This can be seen in the graphs above the range error for for all baselines is very low when at 0 degrees (r1 = r2), but larger baselines have larger range error when at an angle (the larger baseline forces r1 and r2 to be more different at the same angle).

# Conclusions

We learned quite a few things from this project. It was one of our first ventures into anything hardwarerelated, and the hardware choices we made were relatively risky in nature (heavily reliant on an uncommon chip).

### The Only Thing Worse than No Documentation is Wrong/Disorganized Documentation

We ran into lots of problems surrounding the DWM1000 whitepages while writing the SPI drivers. We always identified this as a source of risk in our project, but we perhaps underestimated how much of a source of frustration it would be. The whitepages we had access to were poorly organized, and sometimes solutions to our problems were only mentioned once in a footnote. This wouldn’t be so bad if we were using a popular technology with plenty of online documentation and support. However, the most popular existing open source libraries for the DWM1000 were broken, or “still in development” as they prefer to say. This left us quite alone with the Decawaveprovided documentation.

### Appearances Matter

Most of our project involved building a platform a backend, something people hopefully would never need to think about. While the underlying technology was cool enough for us to be wooed, we did not have enough time to also build a really flashy application on top of the framework. In other words, it was difficult for us to communicate the full complexity and potential of our framework in the demo. We took the time to develop a few example applications on top of our platform, but our efforts were much more focused on the platform itself. Initially we didn’t think this was an issue, but we hadn’t been thinking about the importance of the demo.

### No Risk, No Reward

This should probably be retitled to “We Got Lucky” or perhaps “We Invested Quite a Bit of Time Into Those Drivers”. We took a big risk deciding to have our project rely completely on a single, new module, the DWM1000. We tried to mitigate the risk by breadboarding and creating a prototype as soon as possible, but in the end if we had not succeeded, things would be looking very bad for us. This was a scary possibility hanging over our heads for much of the initial development. For this reason, we almost always were secretly a week ahead of the schedule Aaron was setting for us. This allowed us to guarantee we never missed a weekly demo.

# Related Work

One of the primary reasons we chose our project was to research the feasibility of making angle of arrival calculation using ultrawideband transceivers, as it has not been publicly demonstrated as of yet. There are other solutions that tackle similar issues, though.

For instance, indoor localization systems using wifi

2
, BLE

3
, or even UWB

4 could all be used for similar applications as our system. Wifi and BLE systems are less accurate than UWB, though, and UWB indoorlocalization systems still require installation of at least three Anchors in each area, on separate walls. Our system would be able to support many similar applications (such as those listed in earlier sections) with the installation of a single device (with two contained Anchors) on a wall in the room. The selfcontained property of our Anchors device also means that it could be mounted to something other than a wall, such as a robot, and used to calculate relative range and angle information to a tag from what it is mounted to.

# References

1. http://www.decawave.com/support/download/file/nojs/725
2. http://redpin.org/
3. http://estimote.com/
4. http://www.timedomain.com/
5. https://www.adafruit.com/products/1240

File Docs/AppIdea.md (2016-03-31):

The app idea is to make an Android mobile application which can use data it receives from the server to show the most recent position of the tag being tagged. To do this the Android app will connect to the website and pull information and update the locations of the tags on screen.

The main screen will have dots whcih move around representing different tags. A mockup is attached below - 

Mockup Of Main Page

The dot representing the tag will move around as required. The position of the tag is fixed at the top of the screen and the user will have to orient himself that way as there is no way of knowing which direction the user is relative to the anchors.

It will allow the user to add new tags by entering their tag ID and a name for them. A mockup is below - 

New Tag Menu

This menu comes up when the user presses the plus button to add a new tag. The user can then enter a tag ID and the application will check to make sure it exists and if it does, add it to the main screen.

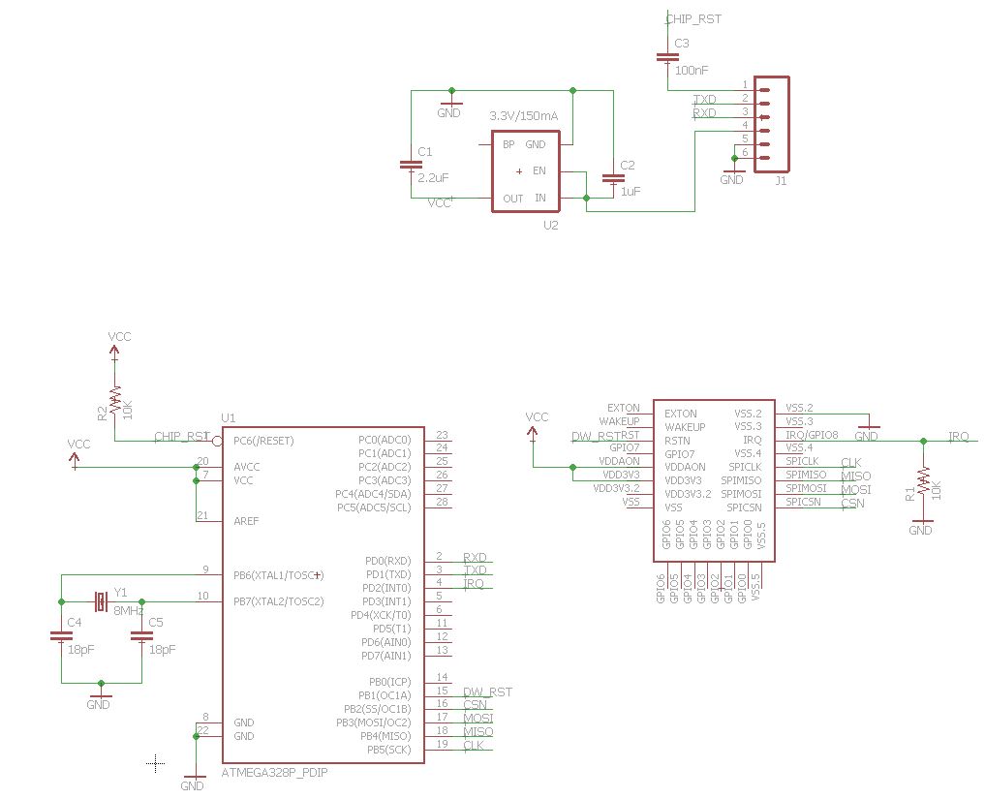
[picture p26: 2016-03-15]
www/images/03.15.16Schematic - Copy.JPG

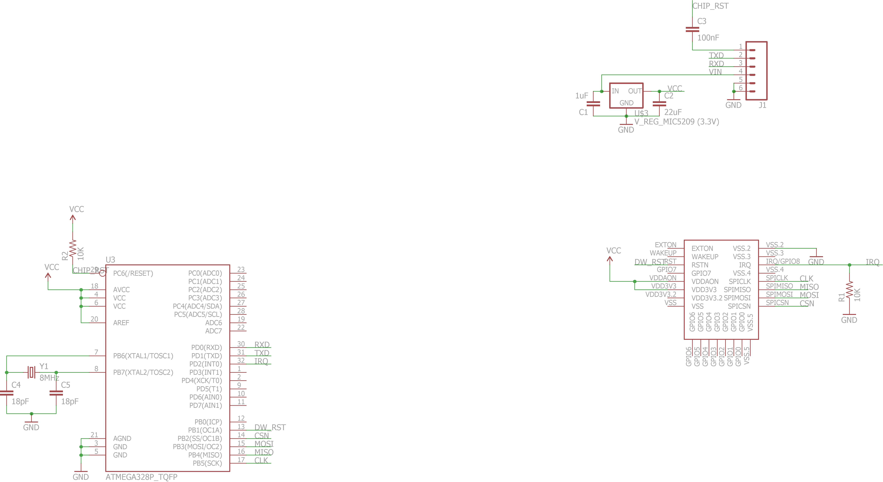
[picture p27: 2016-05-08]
www/images/schematic_final.png

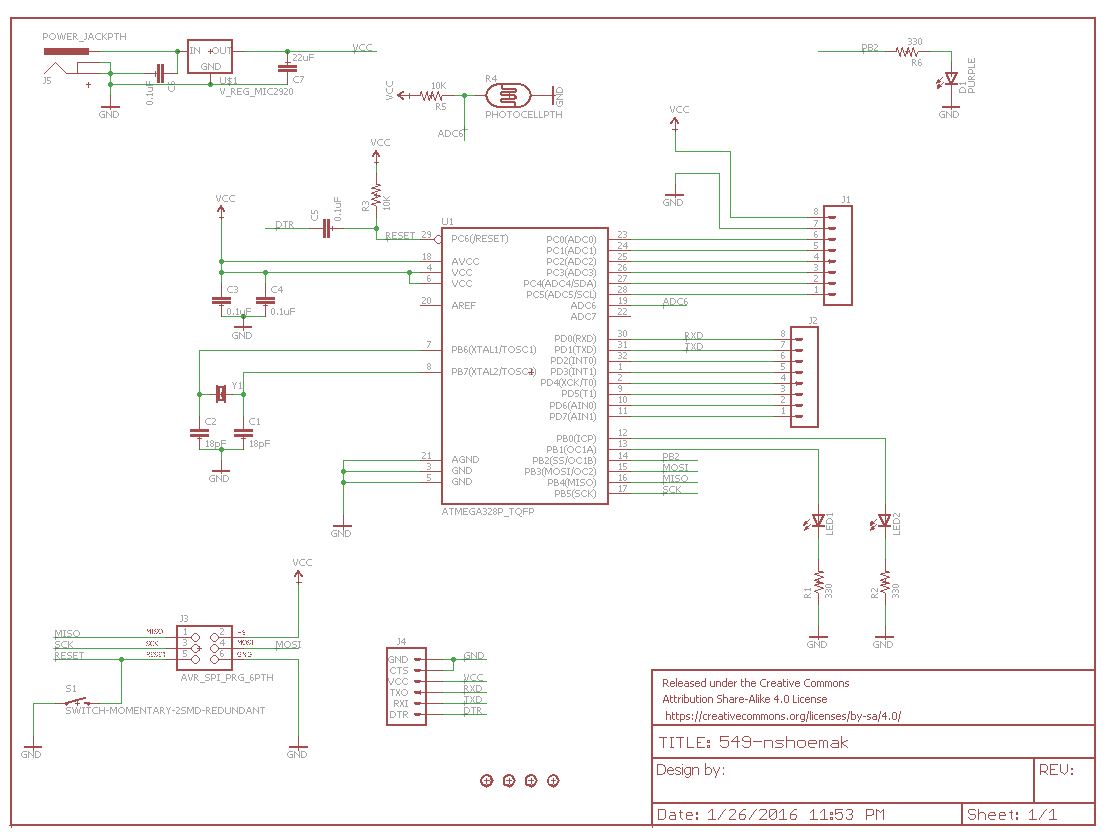
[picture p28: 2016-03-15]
hardware/boards/research/lab1.JPG

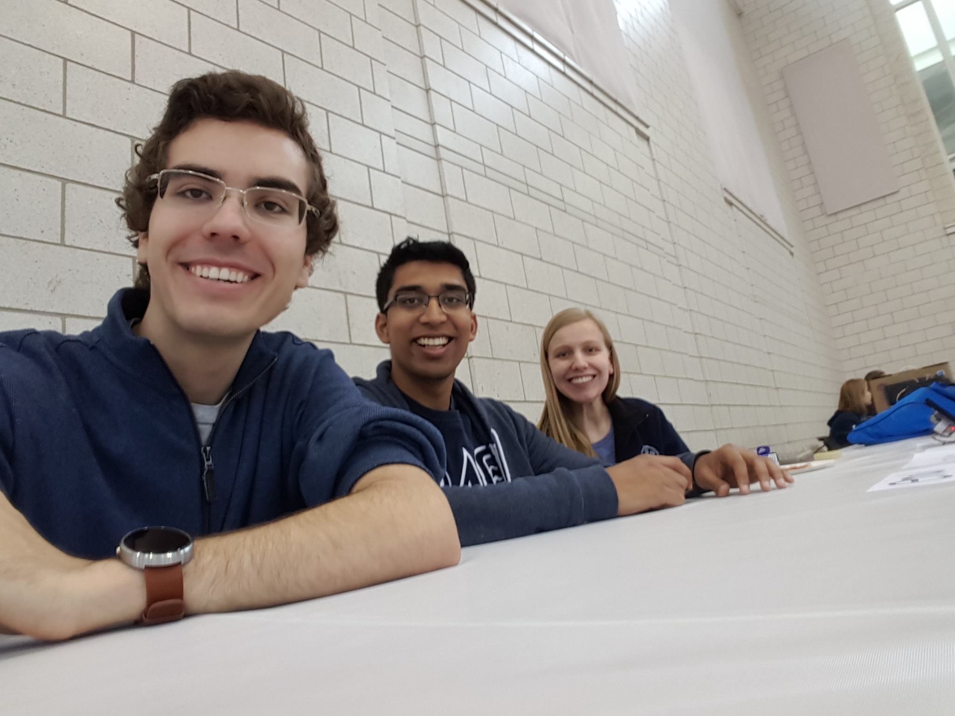
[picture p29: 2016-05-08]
www/images/block6.jpg

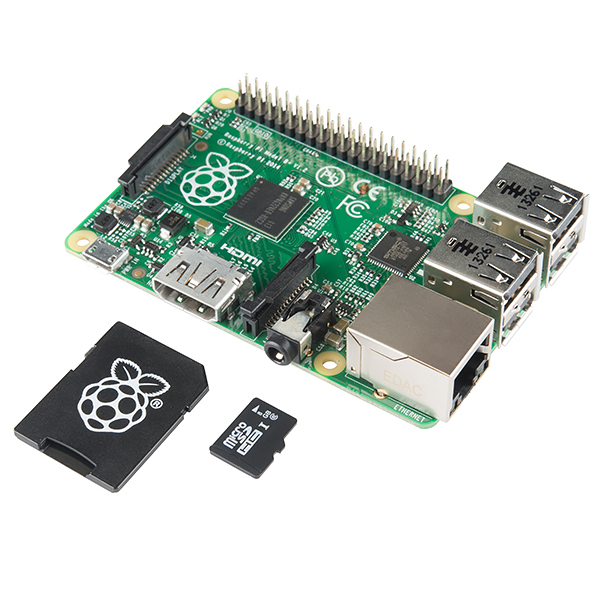
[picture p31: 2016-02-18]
www/images/raspi.jpg

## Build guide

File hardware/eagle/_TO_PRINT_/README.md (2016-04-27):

#BOARD TO PRINT

This folder contains the most recent version of the board we would like to be printed. 

###UPDATE LOG

* 04/06/2016 - folder created.

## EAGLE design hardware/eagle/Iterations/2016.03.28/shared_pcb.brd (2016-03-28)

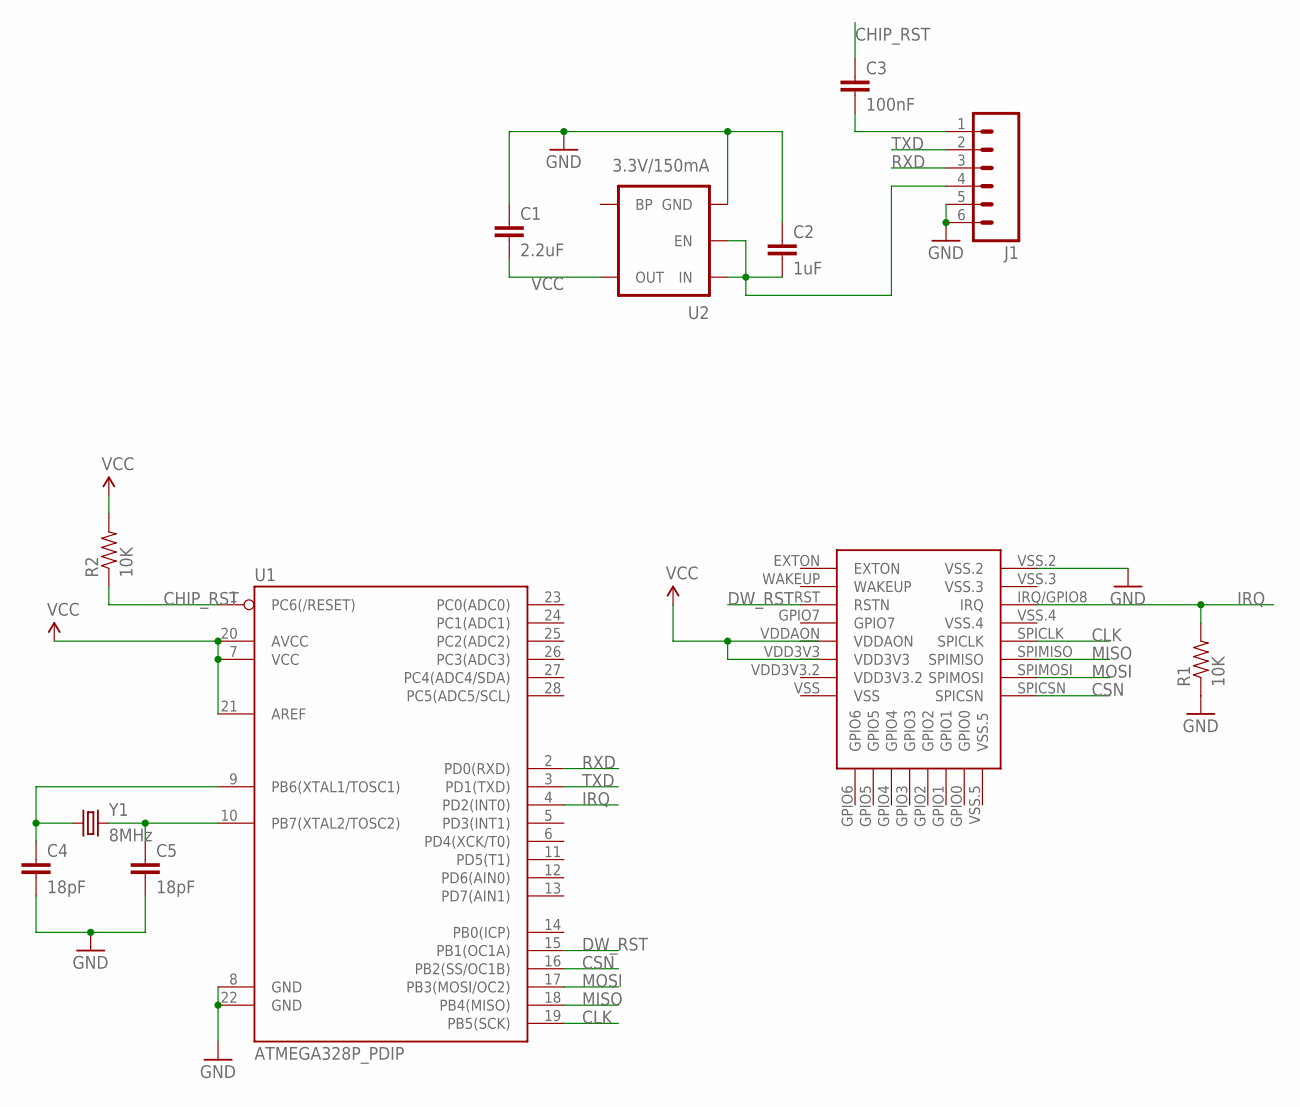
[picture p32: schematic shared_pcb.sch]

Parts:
C1: 2.2uF; 1206
C2: 1uF; 1206
C3: 100nF; 1206
C4, C5: 18pF; 1206
J1: M06LOCK; 1X06_LOCK
R1, R2: 10K; 1206
U1: ATMEGA328P_PDIP; DIL28-3
U2: 3.3V/150mA; SOT23-5
U$1: DWM1000
Y1: 8MHz; CRYSTAL-TXC-7A

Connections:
CHIP_RST: C3.1, R2.1, U1.1 (PC6(/RESET))
CLK: U1.19 (PB5(SCK)), U$1.SPICLK
CSN: U1.16 (PB2(SS/OC1B)), U$1.SPICSN
DW_RST: U1.15 (PB1(OC1A)), U$1.RST (RSTN)
GND: C1.1, C2.1, C4.2, C5.2, J1.5, J1.6, R1.1, U1.8 (GND), U1.22 (GND), U2.2 (GND), U$1.VSS.2
IRQ: R1.2, U1.4 (PD2(INT0)), U$1.IRQ/GPIO8 (IRQ)
MISO: U1.18 (PB4(MISO)), U$1.SPIMISO
MOSI: U1.17 (PB3(MOSI/OC2)), U$1.SPIMOSI
unnamed: C4.1, U1.9 (PB6(XTAL1/TOSC1)), Y1.P$1 (1)
unnamed: C2.2, J1.4, U2.1 (IN), U2.3 (EN)
unnamed: C3.2, J1.1
unnamed: C5.1, U1.10 (PB7(XTAL2/TOSC2)), Y1.P$2 (2)
RXD: J1.3, U1.2 (PD0(RXD))
TXD: J1.2, U1.3 (PD1(TXD))
VCC: C1.2, R2.2, U1.7 (VCC), U1.20 (AVCC), U1.21 (AREF), U2.5 (OUT)

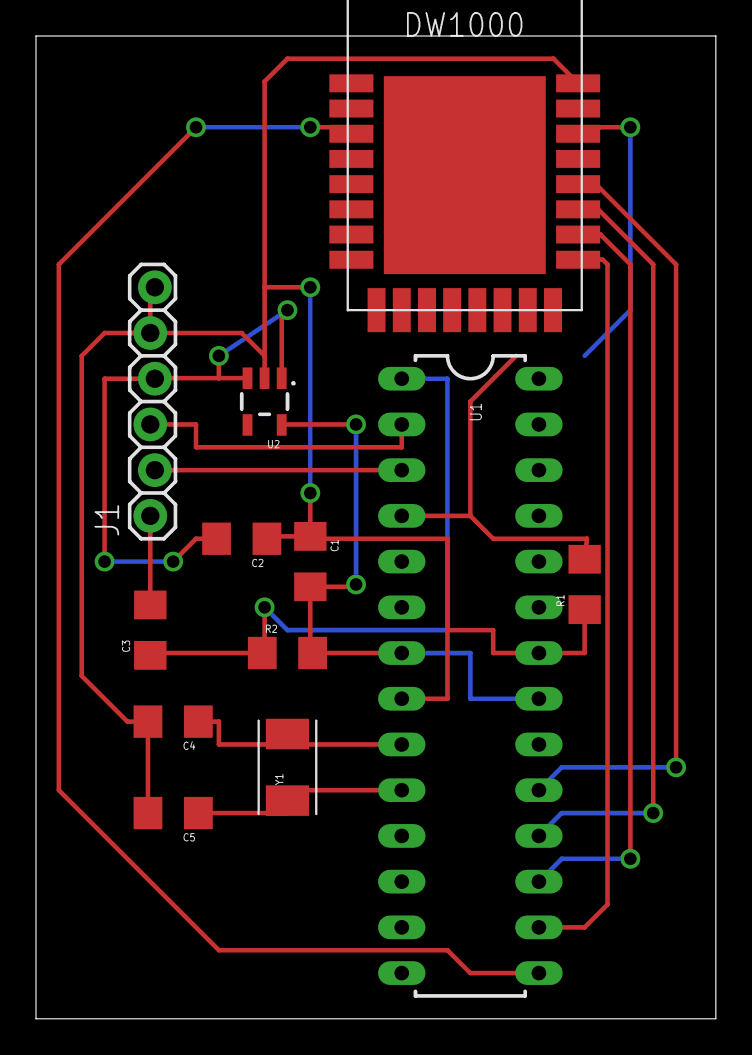
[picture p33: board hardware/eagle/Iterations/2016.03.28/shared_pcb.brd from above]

Board: 2 copper layers, 37.8 x 54.6 mm, 12 parts (0 on the bottom side), 15 nets.

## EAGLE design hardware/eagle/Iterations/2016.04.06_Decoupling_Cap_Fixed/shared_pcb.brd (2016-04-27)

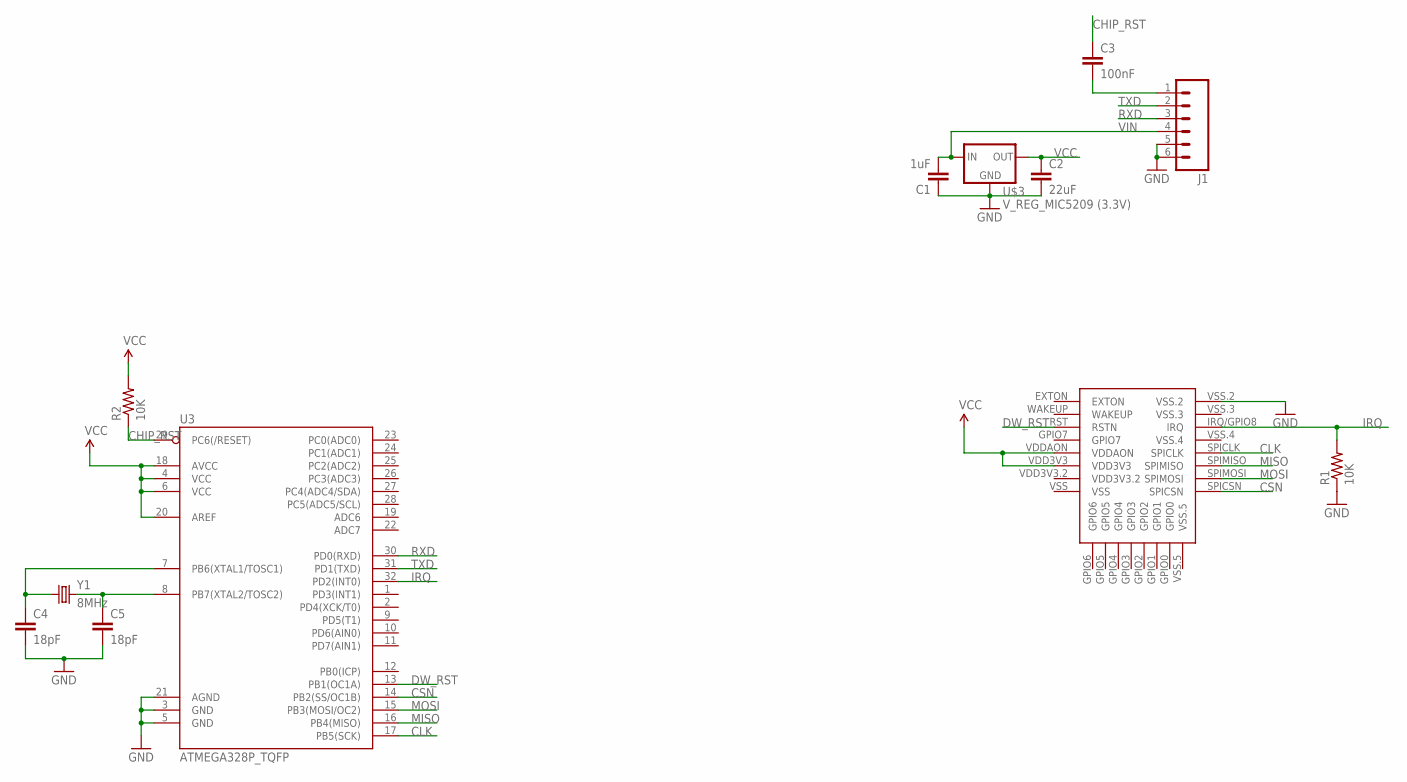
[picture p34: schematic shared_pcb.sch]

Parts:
C1: 1uF; 1206
C2: 22uF; 1206
C3: 100nF; 1206
C4, C5: 18pF; 1206
J1: M06LOCK; 1X06_LOCK
R1, R2: 10K; 1206
U3: ATMEGA328P_TQFP; TQFP32-08
U$1: DWM1000
U$3: V_REG_MIC5209 (3.3V); SOT223
Y1: 8MHz; CRYSTAL-TXC-7A

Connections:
CHIP_RST: C3.1, R2.1, U3.29 (PC6(/RESET))
CLK: U3.17 (PB5(SCK)), U$1.SPICLK
CSN: U3.14 (PB2(SS/OC1B)), U$1.SPICSN
DW_RST: U3.13 (PB1(OC1A)), U$1.RST (RSTN)
GND: C1.1, C2.2, C4.2, C5.2, J1.5, J1.6, R1.1, U3.3 (GND), U3.5 (GND), U3.21 (AGND), U$1.VSS.2, U$3.2 (GND)
IRQ: R1.2, U3.32 (PD2(INT0)), U$1.IRQ/GPIO8 (IRQ)
MISO: U3.16 (PB4(MISO)), U$1.SPIMISO
MOSI: U3.15 (PB3(MOSI/OC2)), U$1.SPIMOSI
unnamed: C3.2, J1.1
unnamed: C4.1, U3.7 (PB6(XTAL1/TOSC1)), Y1.P$1 (1)
unnamed: C5.1, U3.8 (PB7(XTAL2/TOSC2)), Y1.P$2 (2)
RXD: J1.3, U3.30 (PD0(RXD))
TXD: J1.2, U3.31 (PD1(TXD))
VCC: C2.1, R2.2, U3.4 (VCC), U3.6 (VCC), U3.18 (AVCC), U3.20 (AREF), U$1.VDD3V3, U$1.VDDAON, U$3.3 (OUT)
VIN: C1.2, J1.4, U$3.1 (IN)

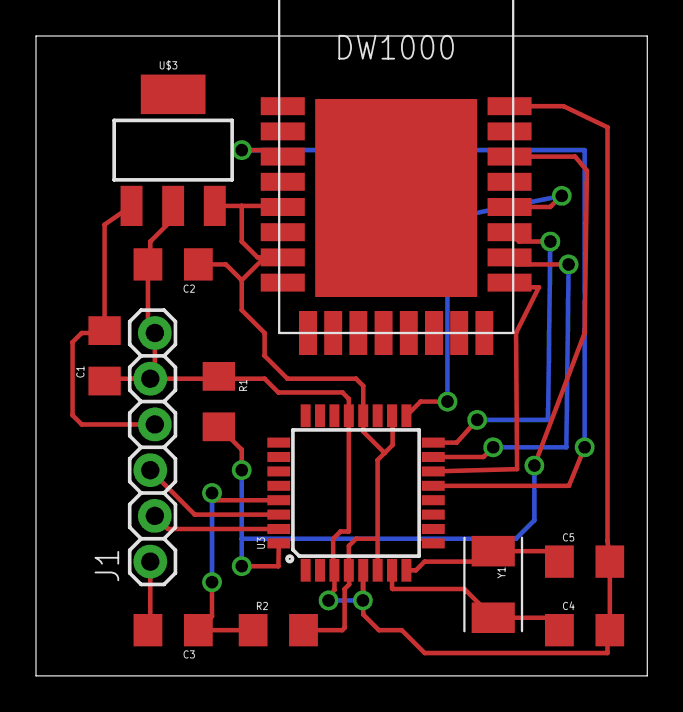
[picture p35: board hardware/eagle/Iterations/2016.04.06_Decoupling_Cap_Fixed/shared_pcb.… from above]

Board: 2 copper layers, 34.0 x 35.5 mm, 12 parts (0 on the bottom side), 15 nets.

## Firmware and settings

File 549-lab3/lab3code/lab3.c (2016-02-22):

#include <Arduino.h>
#include <HardwareSerial.h>

#define NUM_PINS 3

#define RED_PIN 0
#define GREEN_PIN 1
#define BLUE_PIN 2

#define TEMP_PIN A0

int pins[NUM_PINS] = {9, 10, 3};

void setOnlyColor(int pin) {
   for (int i = 0; i < NUM_PINS; ++i) {
      pinMode(pins[i], OUTPUT);
      digitalWrite(pins[i], LOW);
   }
   if (pin < NUM_PINS && pin >= 0) {
      digitalWrite(pins[pin], HIGH);
   }
}

void setAutoColor(int temperature) {
   int minReading = 135;
   int maxReading = 155;
   float scale = ((float)(temperature - minReading)) / (maxReading - minReading);
   scale = (scale < 0.0) ? 0.0 : scale;
   scale = (scale > 1.0) ? 1.0 : scale;
   analogWrite(pins[RED_PIN], scale * 255);
   analogWrite(pins[BLUE_PIN], (1.0 - scale) * 255);
}

int main(void)
{
   char byteRead;
   int temperature;
   bool autoMode = false;
   init();
   Serial.begin(115200);
   setOnlyColor(-1);
   while (1) {
      temperature = analogRead(TEMP_PIN);
      Serial.println(temperature);
      if (Serial.available() > 0) {
         autoMode = false;
         byteRead = Serial.read();
         if (byteRead == 'r') {
            setOnlyColor(RED_PIN);
         } else if (byteRead == 'g') {
            setOnlyColor(GREEN_PIN);
         } else if (byteRead == 'b') {
            setOnlyColor(BLUE_PIN);
         } else if (byteRead == 'o') {
            setOnlyColor(-1);
         } else if (byteRead == 'a') {
            setOnlyColor(-1);
            autoMode = true;
         }
      }
      if (autoMode) {
         setAutoColor(temperature);
      }
      delay(100);
   }

   return 0;
}

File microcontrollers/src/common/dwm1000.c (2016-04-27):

#include "dwm1000.h"

int _makeHeader(byte RW, byte addr, bool isOffset, unsigned int offset, byte* header);
void _readRegister(byte addr, bool isOffset, unsigned int offset, byte* data, unsigned int n);
void _writeRegister(byte addr, bool isOffset, unsigned int offset, byte* data, unsigned int n);
void _setTxConfig(unsigned int msg_len);
void _valToBytes(long val, byte* bytes, int n);
void _setNetworkAddr(unsigned int networkId, unsigned int addr);
void _setAntennaDelays();
void _setChannel();
void _setTransmitPower();
void _setWeirdRegisters();
void _setInterruptMasks();
void _handleInterrupt();
void _sendMessage(byte* data, int len, int destination, int network, Timestamp* t);
void _softReset(bool allBits);
void _handleError();
void _getRxTimestamp(Timestamp* t);
void _getTxTimestamp(Timestamp* t);
void _reverseBytes(byte* b, int len);

byte msgData[MSG_LEN];
byte msgLen = 0;

int _selectPin;
int _resetPin;
int _networkId;
int _addr;
unsigned int _timeout;
byte _irq;

void (*rxFailCallback)(void) = NULL;
void (*generalFailCallback)(void) = NULL;
void (*rxCallback)(Timestamp* t, byte* data, int len, int srcAddr) = NULL;
void (*txCallback)(Timestamp* t) = NULL;

void DW_init(int selectPin, int rstPin, int irq, int networkId, int address, unsigned int timeout) {
	SPI.setClockDivider(SPI_CLOCK_DIV2);
	SPI.setDataMode(SPI_MODE0);
	SPI.setBitOrder(MSBFIRST);

	_irq = irq;
	_networkId = networkId;
	_addr = address;

	_selectPin = selectPin;
	_resetPin = rstPin;
	attachInterrupt(irq, _handleInterrupt, RISING);
	pinMode(selectPin, OUTPUT);
	pinMode(_resetPin, OUTPUT);
	_timeout = timeout;
	DW_reset();
}

void DW_reset() {
	//_softReset(true);
	DW_disableInterrupt();
	digitalWrite(_resetPin, LOW);
	delay(10);
	digitalWrite(_resetPin, HIGH);

	long settings = CONFIG_SETTINGS;
	if (_timeout > 0) {
		_writeRegister(TO_ADDR, false, 0, (byte*)&_timeout, 2);
		settings |= 1L << TO_ENABLE_BIT;
	}
	long b = 0;
	// Don't ask why, but this seems to not fully write at first....
	while (b != settings) {
		_writeRegister(SYS_CONFIG_ADDR, false, 0, (byte*)&settings, 4);
		_readRegister(SYS_CONFIG_ADDR, false, 0, (byte*)&b, 4);
	}

	_setInterruptMasks();
	_setNetworkAddr(_networkId, _addr);
	_setAntennaDelays();
	_setChannel();
	_setTransmitPower();
	_setWeirdRegisters();

	long control = 0;
	control |= 1L << CANCEL_BIT;
	_writeRegister(CONTROL_ADDR, false, 0, (byte*)&control, 4);
	byte p[2];
	p[0] = 0x01;
	p[1] = 0x03;
	_writeRegister(PWR_MGMT_ADDR, true, PWR_MGMT0_SUB, p, 2);
	long d = OTP_CTRL;
	_writeRegister(OTP_ADDR, true, OTP_CTRL_SUB, (byte*)&d, 2);
	delay(10);
	p[0] = 0x00;
	p[1] = 0x02;
	_writeRegister(PWR_MGMT_ADDR, true, PWR_MGMT0_SUB, p, 2);
	DW_enableInterrupt();
}

void getTime(Timestamp* t) {
	_readRegister(SYS_TIME_ADDR, false, 0, (byte*)&t->time, 5);
}

void DW_getDevID(byte* devId) {
	_readRegister(DEVICE_ID_ADDR, false, 0, devId, 4);
}

void _setNetworkAddr(unsigned int networkId, unsigned int addr) {
	byte data[4];
	_valToBytes(addr, data, 2);
	_valToBytes(networkId, data + 2, 2);
	_writeRegister(NETWORK_ADDR_ADDR, false, 0, data, 4);
}

unsigned int DW_getAddr() {
	int addr;
	_readRegister(NETWORK_ADDR_ADDR, true, ADDR_SUB, (byte*)&addr, 2);
	return addr;
}

unsigned int DW_getNetworkId() {
	int id;
	_readRegister(NETWORK_ADDR_ADDR, true, NETWORK_ID_SUB, (byte*)&id, 2);
	return id;
}

void _setTxConfig(unsigned int msg_len) {
	byte config[5];
	long modifiedSettings = TX_SETTINGS | (unsigned long)(msg_len + 2);
	_valToBytes(modifiedSettings, config, 4);
	config[4] = IFS_DELAY;
	_writeRegister(TX_CONFIG_ADDR, false, 0, config, 5);
}

void _valToBytes(long val, byte* bytes, int n) {
	for (int i = 0; i < n; ++i) {
		bytes[i] = ((val >> (i * 8)) & 0xFF);
	}
}

void _setAntennaDelays() {
	int d = ANT_DELAY;
	_writeRegister(TX_ANT_DELAY_ADDR, false, 0, (byte*)&d, 2);
	_writeRegister(LDE_ADDR, true, RX_ANT_DELAY_SUB, (byte*)&d, 2);
}

void _setTransmitPower() {
	long power = TX_POWER;
	_writeRegister(TX_POWER_ADDR, false, 0, (byte*)&power, 4);
}

void _setChannel() {
	long channel = CHANNEL_SETTINGS;
	_writeRegister(CHANNEL_ADDR, false, 0, (byte*)&channel, 4);
}

void _setWeirdRegisters() {
	long data;
	
	data = AGC1;
	_writeRegister(AGC_ADDR, true, AGC1_SUB, (byte*)&data, 2);
	data = AGC2;
	_writeRegister(AGC_ADDR, true, AGC2_SUB, (byte*)&data, 4);
	data = AGC3;
	_writeRegister(AGC_ADDR, true, AGC3_SUB, (byte*)&data, 2);

	data = DRX0B;
	_writeRegister(DRX_ADDR, true, DRX0B_SUB, (byte*)&data, 2);
	data = DRX1A;
	_writeRegister(DRX_ADDR, true, DRX1A_SUB, (byte*)&data, 2);
	data = DRX1B;
	_writeRegister(DRX_ADDR, true, DRX1B_SUB, (byte*)&data, 2);
	data = DRX2;
	_writeRegister(DRX_ADDR, true, DRX2_SUB, (byte*)&data, 4);
	data = DRX4;
	_writeRegister(DRX_ADDR, true, DRX4_SUB, (byte*)&data, 2);

	data = RFRX;
	_writeRegister(RF_CONF_ADDR, true, RFRX_SUB, (byte*)&data, 1);
	data = RFTX;
	_writeRegister(RF_CONF_ADDR, true, RFTX_SUB, (byte*)&data, 4);

	data = TC_PGDELAY;
	_writeRegister(TX_CAL_ADDR, true, TC_PGDELAY_SUB, (byte*)&data, 1);

	data = FS_PLL_CFG;
	_writeRegister(FS_CTRL_ADDR, true, FS_PLL_CFG_SUB, (byte*)&data, 4);
	data = FS_PLL_TUNE;
	_writeRegister(FS_CTRL_ADDR, true, FS_PLL_TUNE_SUB, (byte*)&data, 1);

	data = LDE2;
	_writeRegister(LDE_ADDR, true, LDE2_SUB, (byte*)&data, 2);
	data = LDE_REPC;
	_writeRegister(LDE_ADDR, true, LDE_REPC_SUB, (byte*)&data, 2);

	data = OTP_CTRL;
	_writeRegister(OTP_ADDR, true, OTP_CTRL_SUB, (byte*)&data, 2);	
}

void _setInterruptMasks() {
	byte data[4];
	long mask = 0;
	mask |= 1L << TX_DONE_BIT;
	mask |= 1L << RX_DONE_BIT;
	mask |= 1L << PREAMBLE_ERR_BIT;
	mask |= 1L << HEADER_ERR_BIT;
	mask |= 1L << RX_TO_BIT;
	mask |= 1L << CLOCK_ERR_BIT;
	mask |= 1L << TOO_LATE_BIT;
	_valToBytes(mask, data, 4);
	long status = 0;
	_writeRegister(STATUS_ADDR, false, 0, (byte*)&status, 4);
	_writeRegister(INTERRUPT_MASK_ADDR, false, 0, data, 4);
}
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

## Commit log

2016-02-19 Added UART and FTDI info. Also cleaned up a few of the images.
2016-03-04 Added offset reading and writing over SPI. Also added reading and writing of network and device address. The device address is passed through a command line argument to the makefile
2016-03-15 Adding initial schematic
    [shared_pcb.sch]
2016-03-18 Interrupts seem to be working. Transmission is tentatively working, though I have not tried reception yet so who knows.
2016-03-19 Receiving is working!!!! Kinda. Fails after one message
    [dwm1000.c, dwm1000.h]
2016-03-20 Handling reception errors better. No crashing but every other message is dropped.
    [dwm1000.c, dwm1000.h]
2016-03-26 Modified the DWM code to expose client callbacks for reception, failed reception, and transmission.
    [dwm1000.c, dwm1000.h]
2016-03-28 Eagle schematic and layout
    [shared_pcb.brd, shared_pcb.sch]
2016-03-29 Push sample
2016-04-02 Adding tinyserial files to replace hardwareserial.
    [tinyserial.h]
2016-04-02 Fixed LDE load code.
    [dwm1000.c]
2016-04-03 Add schematic/layout backup
    [shared_pcb.brd, shared_pcb.sch]
2016-04-03 Add schematic/layout with AVR Programmer
    [shared_pcb.brd, shared_pcb.sch]
2016-04-03 Add schematic/layout for SMD without AVR
    [shared_pcb.brd, shared_pcb.sch]
2016-04-03 Propogation time estimates are stable!!!! They still need antenna delay calibration.
2016-04-03 Pretty accurate! (20-30 cm at worse when under 5m).
2016-04-04 Adding a logo bitmap for the pcb.
2016-04-06 pcb-fix decoupling cap around voltage regulator
    [shared_pcb.brd, shared_pcb.sch]
2016-04-06 Moving hardware files into folder
    [shared_pcb.sch]
2016-04-06 pcb - moving other cap towards v reg
    [shared_pcb.brd, shared_pcb.sch]
2016-04-06 pcb - adding silkscreen
    [shared_pcb.brd, shared_pcb.sch]
2016-04-06 pcb - add gerber files for board to be printed
    [shared_pcb.brd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]
2016-04-06 pcb - add _TO_PRINT_ folder
    [shared_pcb.brd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]
2016-04-06 Moving old boards into Iterations folder
    [shared_pcb.brd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]
2016-04-06 Added resets of the DWM after each range.
    [dwm1000.c, dwm1000.h]
2016-04-07 Added periodic resetting and bettor error handling.
    Tried a 35+ meter test and accuracy was within 10 cm.
    [dwm1000.c, dwm1000.h, ranging.h]
2016-04-10 Added command line options for antenna delays and made delays.txt to keep track of the delays for each board.
2016-04-11 Added error checking for wifi when the raspi starts up
    [demoGet.py]
2016-04-16 Fixed the weird issue where the first anchor and the second anchor needed different antenna delays.
    [dwm1000.c]
2016-04-16 Got rid of extra print statements
2016-04-18 Commiting udpated raspberry pi files
2016-04-18 Changed code so that calls to server run on separate thread
2016-04-18 Changed timer to 3s instead of 300ms
2016-04-18 Updated the dwm rates to be much faster (10 Hz).
2016-04-18 Resetting the anchors on startup of raspi code.
    [demoGet.py, serialRaspi.py]
2016-04-27 Adjusted antenna delays for new tag enclosure
2016-04-29 Current version of the app. About to start trying to only chage the room size
2016-04-30 Now has a cancel button to leave picture and go back to Original page

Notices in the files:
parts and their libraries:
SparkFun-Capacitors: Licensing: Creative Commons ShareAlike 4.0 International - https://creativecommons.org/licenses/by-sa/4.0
